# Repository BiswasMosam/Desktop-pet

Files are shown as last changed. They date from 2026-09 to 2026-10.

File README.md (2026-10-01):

# Desktop-pet

A tiny desk companion with a face. Two rounded eyes on a 0.96" OLED that glance around, blink, fidget, light up when you pet it and doze off when you ignore it. Plugged into the PC it becomes the physical face of [Aminal](https://github.com/BiswasMosam/Aminal-Public), my voice assistant: its eyes listen, think and talk along with it, and it shows the time, the weather, timers and reminders.

It follows the PC too: it dances to your music, eats popcorn through films, puts on glasses while you code, picks up a controller when you play, and counts down your selfies. And it doesn't need the cable: on a charger it reaches the PC over WiFi, and with the PC off it fetches its own time and weather.

<p>
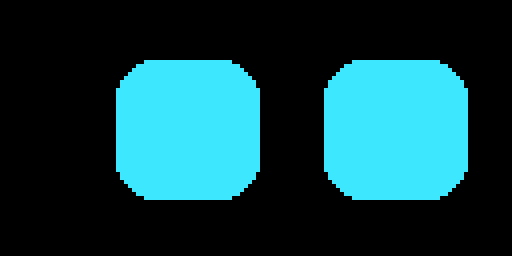
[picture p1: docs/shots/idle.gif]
Idle: glancing around and blinking
  
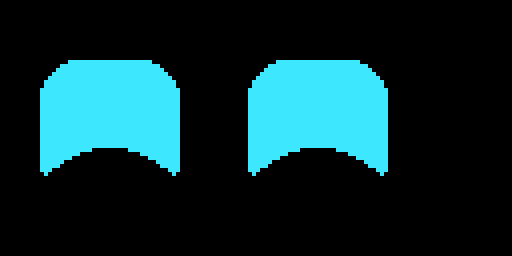
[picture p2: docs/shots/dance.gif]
Dancing to music, notes floating up
  
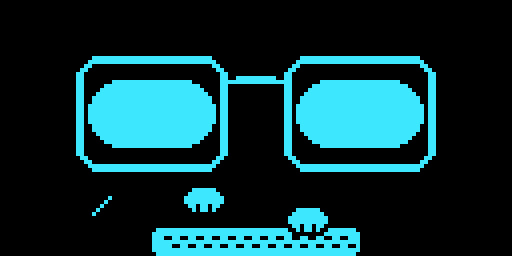
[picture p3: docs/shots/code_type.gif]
Coding: glasses on, paws typing
  
</p>

Real captures from the pet's own frame buffer: idle, dancing, and typing along while you code.

**[The handbook](https://www.mosambiswas.com/Desktop-pet/)** is the full user guide and technical notes: every face, trick and screen, the wiring, the firmware, the protocol and how it hears music. It's also a 25-page [PDF](docs/Desktop-pet-Handbook.pdf).

## What it does

### The face

| Expression | When | What you see |
| --- | --- | --- |
| **Idle** | Default | Glances around every 1.5 to 4 s, blinks, and every 15 to 40 s fidgets: a look around, a little hop, a suspicious squint or a double blink |
| **Happy** | You tap KEY | Eyes lift and curve into `^ ^` arcs for 2.5 s |
| **In love** | Three taps in a row | Beating hearts |
| **Sleepy** | 30 s with no attention (10 s after 11 pm) | Eyes droop into slits, `z`s bob in the corner, and the time shows small in the other |
| **Listening** | Aminal is listening | Eyes wide open, swelling with your voice |
| **Thinking** | Aminal is working it out | Looking up and off to one side, three dots filling in |
| **Speaking** | Aminal is talking | Eyes lifted, and a mouth that opens with Aminal's voice |

Aminal can also make it pull a face on request: happy, love, surprised, sad, angry, wink or sleepy.

Everything moves by easing the current eye position, width and height toward a target every frame, so glances glide, blinks snap shut and falling asleep is a slow droop rather than a jump cut.

### The other screens

- **Clock:** big time, the date, and a hairline filling across the minute.
- **Weather:** an animated icon (turning sun, crescent moon at night, falling rain, drifting snow, flickering lightning, rolling fog), the temperature, today's high and low, and the place.
- **Timer:** the countdown with a bar draining under it. It blinks while paused, and when it runs out the whole screen flashes "Time's up" until you tap it.
- **Claude:** how much of your Claude plan is used, the way Claude's own Usage settings show it: the current session and the week, each with a bar and when it resets. From 90% the number turns over, white on black. The bridge reads it every 2 minutes with the sign-in Claude Code keeps on the PC, and only the four numbers reach the pet. The page joins the round once there are numbers to show.
- **Status:** which link it's on, what Aminal is doing, and how fresh the time and weather are.

Reminders, mail and what's next on the calendar slide down as a card over whatever is on screen. Ask Aminal for the weather or a timer and the pet flips to that screen while it answers.

### Music and films

When Aminal hears Spotify playing, the pet joins in, in one of three moods picked at random and rerolled every 25 to 45 s:

| Mood | What you see |
| --- | --- |
| **Headphones** | Headphones on, eyes shut and happy, nodding on every beat, with a peek around now and then |
| **Dancing** | Swaying side to side and hopping on the beat, music notes floating up |
| **Visualizer** | The whole screen becomes 16 bars of what the speakers are actually playing, with falling peak marks |

Put on Netflix, Prime Video or Hotstar and it looks up at the screen with a bucket of **popcorn**, flicking a kernel into its mouth and chewing every few seconds. When a scene suddenly gets loud it jumps, and the popcorn flies out of the bucket.

Aminal decides music or film by the app and the tab title, never by guesswork, so a video call gets no reaction at all. The beats and bars come from Aminal listening to the speakers; without them the pet dances to a steady 115 bpm of its own.

### Coding and gaming

The pet also follows what's in front on the PC:

| In front | What you see |
| --- | --- |
| **Code** (VS Code, Cursor, a JetBrains IDE, a terminal, GitHub or Colab in a browser) | Glasses on, reading along each line and down the page. While you type, two paws tap on a little keyboard and code flies off its ends |
| **A game** (anything from a Steam, Epic, Riot, Xbox, EA, Ubisoft, GOG or Rockstar library, a few by name, or any exclusive full screen 3D app) | Eyes narrowed in focus and darting after the action, a controller in its hands with the buttons getting mashed. When the game gets loud, sparks burst out and the eyes pop wide |

With music playing as well it keeps the coding or gaming face and puts the headphones on over it, nodding on the beat. An editor nobody has touched for five minutes isn't coding, and a few seconds in front are needed before either counts, so alt-tabbing past VS Code changes nothing. Aminal goes by the program, its folder and the window title only, never by what's in the window or what's typed.

### The card

Tap the RFID card on the reader and a hidden folder opens on the PC (`C:\Users\<you>\Vault`, hidden and marked as a system folder so it stays out of sight even with hidden files shown). Tap again and it closes. The first card ever tapped becomes the key; any other card gets a sad face. It works with Aminal closed, since the bridge does it.

A tap is the card arriving after being away for 1.5 s, so a card left lying on the reader counts once. Gestures (double tap, hold to lock) and a "hotel key slot" came first and both glitched: a card resting on the reader drops out of reading for over a second now and then. Hidden is not locked: anyone who types the path can open the folder.

### Selfies

Ask Aminal for a selfie and the pet turns into a camera. While the webcam opens and meters, its lens focuses and searches for you ("smile please!"). As Aminal says "Hold still - three, two, one", the numbers count down inside the lens, then "cheese!". The moment the photo is actually taken, the screen flashes white and the shutter blinks closed and open ("click!"), and it says "developing" until Aminal has the picture ready.

The flash is the real shutter, not a timer: the photo burst starts the instant "three, two, one" ends, and the bridge flashes the pet on exactly that, because the voice takes anywhere from 1.9 to 2.4 s to say it.

### The button

KEY (PA0) is the only input, or a TTP223 touch pad on B0 under the top of the [enclosure](enclosure/), which does exactly the same:

| Press | On the face | Anywhere else |
| --- | --- | --- |
| **Tap** | Pet it | Next screen |
| **Double tap** | Next screen | Next screen |
| **Hold** | Back to the face | On the timer: pause or resume it. Elsewhere: back to the face |

A tap also dismisses a card. A screen you flipped to returns to the face after 20 s.

## Hardware

- **WeAct Black Pill**, STM32F401CC or STM32F411CE
- **0.96" SSD1306 OLED**, 128x64, I2C
- **ESP-01** WiFi module (optional): its own time and weather when the PC is off, and the link to the PC with no cable
- **RC522** RFID reader (optional): tap a card to open a hidden folder
- **TTP223** touch sensor (optional): pet it by touching the top of its head
- USB-C cable

### Wiring

| OLED | Black Pill |
| --- | --- |
| VCC | 3V3 |
| GND | GND |
| SCL | B6 |
| SDA | B7 |

| ESP-01 | Black Pill |
| --- | --- |
| 3V3 (VCC) | 3V3, with **short direct wires**. **Never 5V**. Long breadboard jumpers made it brown out whenever its radio worked; short ones on the Black Pill's own 3V3 are fine |
| GND | G |
| EN (CH_PD) | A8 (the pet holds it high, which saves a 3V3 pin) |
| TX | A10 |
| RX | A9 |
| RST | B12 (lets the pet restart it) |
| GPIO0 | B13 (lets the pet start its bootloader) |

| RC522 | Black Pill |
| --- | --- |
| 3.3V | 3V3. **Never 5V** |
| GND | G |
| SDA | A4 |
| SCK | A5 |
| MISO | A6 |
| MOSI | A7 |
| RST | B1 (the pet drives it; left floating, the chip can sleep and stop answering) |
| IRQ | not connected |

| TTP223 | Black Pill |
| --- | --- |
| VCC | B14 (it draws microamps, so a pin powers it) |
| GND | B15 |
| I/O | B0 (not A0: the bootloader reads A0 at reset, and the pad's output sits low) |

The board has three 3V3 pins and three G pins (two on the long headers, one each on the small 4-pin header): one pair each for the OLED, the ESP-01 and the RC522. Both 5V pins stay empty.

The ESP-01's pins aren't labelled on top. With the chips facing you and the antenna up, one row holds GND, GPIO2, GPIO0 and RX, the other TX, EN, RST and 3V3; GND and 3V3 sit at opposite corners. GPIO2 stays empty.

The KEY button (PA0) and the blue LED (PC13) are already on the board.

### The enclosure

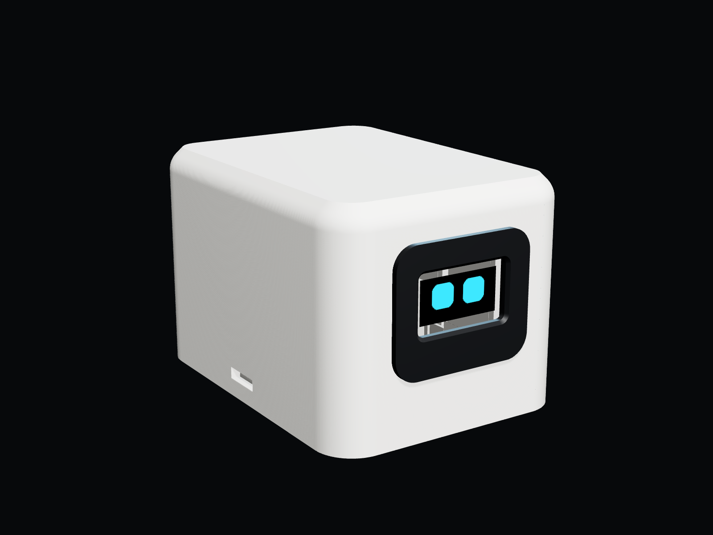
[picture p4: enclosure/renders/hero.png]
The pet in its printed head
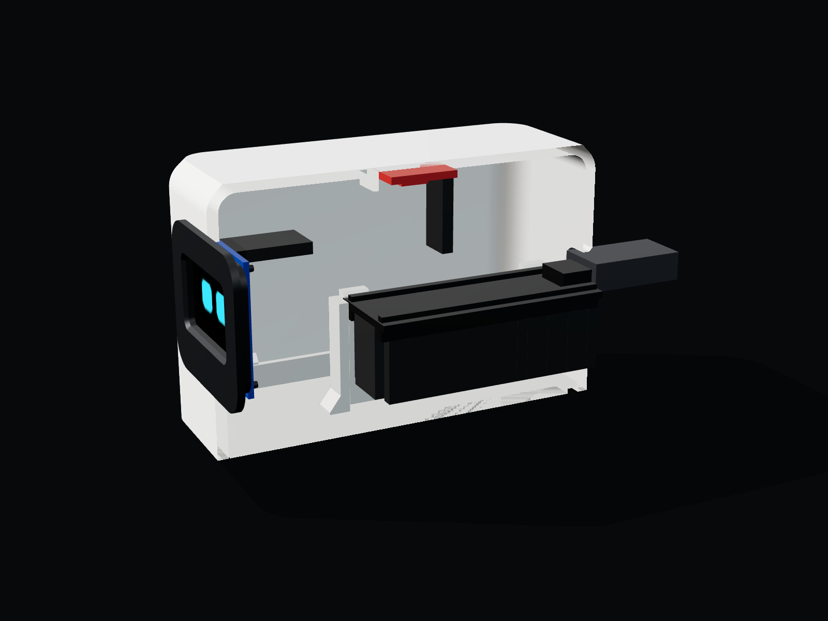
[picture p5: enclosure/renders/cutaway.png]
The head cut open
 

A 3D-printable head, 66 × 89.5 × 58 mm: a soft cube, the screen clamped behind a black visor, the Black Pill held up by its edges so its jumper plugs and SWD header hang free underneath, its USB-C lined up with a port in the back, the touch pad under the top, and the RFID reader hidden inside the right side, with nothing on the outside to give it away. Three parts, no supports. The STLs, print settings and how to put it together are in [enclosure/](enclosure/).

## Getting it running

WeAct Black Pills ship with the **WeAct HID bootloader** in the first 16 KB of flash. It shows up in Windows as a plain HID device (`0483:572A`), so it needs no driver and no Zadig, and it sidesteps the chip's built-in USB bootloader, which often fails with *Device Descriptor Request Failed*. The project is linked to start at `0x08004000`, right after it.

1. **Install PlatformIO.** In VS Code, open Extensions, search for *PlatformIO IDE*, install it and let it finish its first time setup.
2. **Get the uploader.** Download [`WeAct_HID_Flash-CLI.exe`](https://github.com/WeActStudio/WeActStudio.MiniSTM32F4x1/tree/master/Soft/WeAct_HID_FW_Bootloader) from WeAct's repo and save it as `tools/WeAct_HID_Flash-CLI.exe` in this folder. It's WeAct's own tool, closed source, so it isn't committed here.
3. **Open the project.** File > Open Folder > `Desktop-pet`. PlatformIO fetches the STM32 toolchain and the Adafruit display libraries on its own.
4. **Enter the bootloader.** A fresh board is already in it. Once your code is on it, hold **KEY**, tap NRST, wait for the blue LED to blink, then release KEY.
5. **Upload.** Click the → arrow in the blue status bar.
6. The eyes appear. If they don't, tap NRST.

The default build targets the F401CC and also runs on an F411CE. For the F411's full 100 MHz, read the square chip and, if it says `STM32F411CE`, change `default_envs` in `platformio.ini` to `blackpill_f411ce`.

### Connecting it to Aminal

A small bridge on the PC finds the pet on USB by its identity (`0483:5740`) and starts talking. It starts at login and runs whether Aminal is open or not, so the pet follows the music, films, code and games on the PC all day and gets the time, weather and timers; Aminal only adds its listening, thinking and speaking faces. If the bridge isn't running, Aminal starts it.

The cable isn't needed. With only a power cord on the pet, the bridge reaches it over WiFi: the ESP-01 listens on port 7676 and the bridge speaks the same protocol to it as over USB. It learns the pet's address whenever it's plugged in, and searches the home network for it if that address stops answering. USB always wins when it's plugged in. Anyone on the same network can reach that port too, so it's meant for a home network; joining WiFi (`WF`) and the ESP passthrough (`ES`) stay USB only. It can also save exactly what the OLED shows as a PNG (`SN`) or send the pet a single line. Aminal's code is private; its own README has the exact commands.

### WiFi

The ESP-01 keeps its factory **AT firmware**, and the pet drives it with plain text commands: join the network, then one plain-HTTP request to Open-Meteo every 20 minutes. That single reply carries the time (its `Date` header), the UTC offset and today's weather, so a pet running from a charger keeps its clock and forecast with the PC off. Where the weather is for (`LO`, sent by Aminal) and the UTC offset are kept in the Black Pill's flash across power cuts.

It also listens on port **7676** for the bridge, which is how the pet works with only a power cord (above). The module's multi-link mode makes that possible: the weather request goes out on link 4 while the bridge comes in on another. While the bridge is connected over WiFi it sends the time and weather itself, so the pet skips its own request. The pet resets the module at every boot, and again if it stops answering, so a bad power-up can't leave the WiFi stuck.

To connect it, run the bridge's WiFi setup with the pet on USB. It offers the network the PC is on, asks for the password without showing it, and sends both down the USB cable only. The module keeps them and rejoins by itself from then on. The ESP8266 only does **2.4 GHz** networks.

Reflashing the ESP-01 with firmware of its own, through the pet, was tried and failed: its ROM loader restarts on every esptool SYNC. The pet can still talk to it directly for debugging (`ES talk`), and every reset it does reports the ROM's own start-up line (`ES boot ets Jan 8 2013,rst cause:2, boot mode:(3,6)`), read at 74880 baud.

USB always wins. The bridge tries the cable first and WiFi every 15 s while the pet isn't plugged in, and plugging the cable back in moves the link to USB by itself. Running the pet from a phone charger or power bank is how it goes wireless: about 20 to 30 s after it powers up, the bridge reaches it over WiFi. Everything works over WiFi: a full `SN` snapshot takes about 0.4 s.

## The protocol

One short line per message, the same on USB and WiFi, simple enough to type into a serial monitor:

| Line | Meaning |
| --- | --- |
| `HI` | Who are you? The pet answers `PET desktop-pet 11` |
| `IP` | Its WiFi address: `IP 192.168.1.12`, or `IP -` when it isn't online |
| `PG` | Heartbeat, answered `PO`. Eight silent seconds and the pet is on its own again |
| `ST idle\|listening\|thinking\|speaking\|off` | What Aminal is doing |
| `LV 0-100` | Voice level, for the eyes and the mouth |
| `TM <unix> <utc offset s>` | The time |
| `WX <temp> <wmo code> <hi> <lo> <place>` | The weather |
| `TI <left s> <total s> <paused 0/1> <label>` or `TI -` | The timer, or none |
| `AL <secs> <title>\|<text>` or `AL -` | A card, or take it down |
| `EM <happy\|love\|surprised\|sad\|angry\|wink\|sleepy> [ms]` | Pull a face |
| `GO <face\|clock\|weather\|timer\|usage\|status> [secs]` | Show a screen |
| `CU <session %> <reset> <week %> <reset>` | Claude's usage, each reset as Unix time |
| `SN` | Answered `SN <hex>`: the 1024-byte frame buffer, exactly what's on the OLED |
| `RF`, `RF test`, `RF poll` | The RC522: its chip version; a wiring test (a register written and read back, and whether anything drives MISO); one try at reading a card |
| `MD music [headphones\|dance\|bars]`, `MD watch`, `MD -` | What's playing; a mood can be asked for by name |
| `VZ <16 hex digits>` | Spectrum bars, 0 to f each, low to high |
| `BE` | A beat |
| `JS` | A sudden loud moment in a film or a game |
| `AC code [typing]`, `AC game`, `AC -` | What's in front on the PC |
| `SF ready`, `SF count <ms>`, `SF shot`, `SF -` | A selfie: the camera opening, the spoken countdown, the shutter, done |
| `LO <lat> <lon> <place>` | Where the weather is for; kept in flash for the WiFi to use |
| `WF <ssid><tab><password>` | USB only: join a WiFi network (the ESP-01 keeps it) |
| `ES talk\|flash [baud]`, `ES reset` | USB only: the cable straight through to the ESP-01, in its own program or its bootloader, until 12-30 s of quiet |

The pet sends events back: `EV pet`, `EV next <screen>`, `EV hold`, `EV hold timer`, `EV dismiss`, `EV wifi ok <ip>`, `EV wifi fail`, `EV card <uid> tap`.

## Troubleshooting

| Symptom | Likely cause |
| --- | --- |
| Blue LED blinks fast, screen blank | OLED not found on I2C. Check the four wires, then try `0x3D` for `OLED_ADDR` in `src/main.cpp`. |
| Upload can't find the board | Board isn't in the HID bootloader. Hold KEY, tap NRST, release KEY when the LED blinks. |
| Upload says the command isn't found | `tools/WeAct_HID_Flash-CLI.exe` is missing (step 2). |
| No HID device at all, even holding KEY | The HID bootloader was erased (a DFU or ST-Link upload to `0x08000000` does that). Reflash it from WeAct's repo, or drop `board_build.flash_offset` and upload over DFU or ST-Link instead. |
| Don't install WinUSB over *WeAct Studio HID Bootloader* in Zadig | The uploader talks to it as HID. If you already did, uninstall that device in Device Manager and replug. |
| Garbage or noise on screen | Module may be an SH1106 (common on 1.3" boards), which needs a different library. |
| Eyes never react to Aminal | Status screen says `Link none`: the bridge isn't running, or something else (a serial monitor) has the port open. |
| ESP-01 answers `AT` but garbles its replies, restarts or goes silent while joining or scanning | Brownout. Its radio pulls ~300 mA bursts: serial turns to garbage (`AT+CWLAP` echoed as `AfWLAP`), then it crashes. Lowering its transmit power (`AT+RFPOWER`) didn't help. The cause here was the wiring, not the regulator: long breadboard jumpers drop too much voltage under those bursts, and short direct wires fixed it. If it still drops out on short wires, give it its own **AMS1117-3.3** on the 5V pin with a 470 µF capacitor. |

## How the code is laid out

| File | What's in it |
| --- | --- |
| `src/pet.h` | The shared `World`: time, weather, timer, Aminal's state, the current card |
| `src/main.cpp` | Setup, the frame loop, the button, switching screens |
| `src/face.cpp` | Eyes, moods, fidgets, and the listening, thinking and speaking faces |
| `src/screens.cpp` | Clock, weather icons, timer, Claude's usage, status, and the alert card |
| `src/media.cpp` | Headphones, music notes, the visualizer, and the popcorn |
| `src/activity.cpp` | Glasses, the keyboard and paws, the controller, and the sparks |
| `src/camera.cpp` | The camera face for a selfie: countdown, flash and shutter |
| `src/rfid.cpp` | The RC522: polling for a card, and turning a card's arrival into a tap |
| `src/link.cpp` | The protocol, read from USB and WiFi alike, and the ESP-01 passthrough |
| `src/wifi.cpp` | The ESP-01 driven through its AT firmware: joining, the HTTP request, reading the reply |

All timers compare with `reached(now, t)` instead of `now > t`, so the pet keeps blinking after `millis()` wraps around at about 49.7 days.

The saved location lives in the chip's last flash sector (0x08020000 on the F401CC). The app starts at 0x08004000 and is about 98 KB, so it has about 14 KB of room before the two would meet.

## Stack

C++ on the Arduino framework (STM32duino), built with PlatformIO. Adafruit SSD1306 and Adafruit GFX for the display, FreeSans Bold for the big digits.

## Next

- The touch pad, once it arrives (the firmware already powers and reads it)

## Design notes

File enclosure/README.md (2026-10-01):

# The enclosure

A head for the face: a soft cube, the screen behind a black visor, the Black Pill up on a stand inside, a touch pad under the top so you pet it where you'd pet a pet, and the RFID reader hidden inside its right side, so you tap your card on its cheek. Nothing on the outside gives it away.

The pet in its head

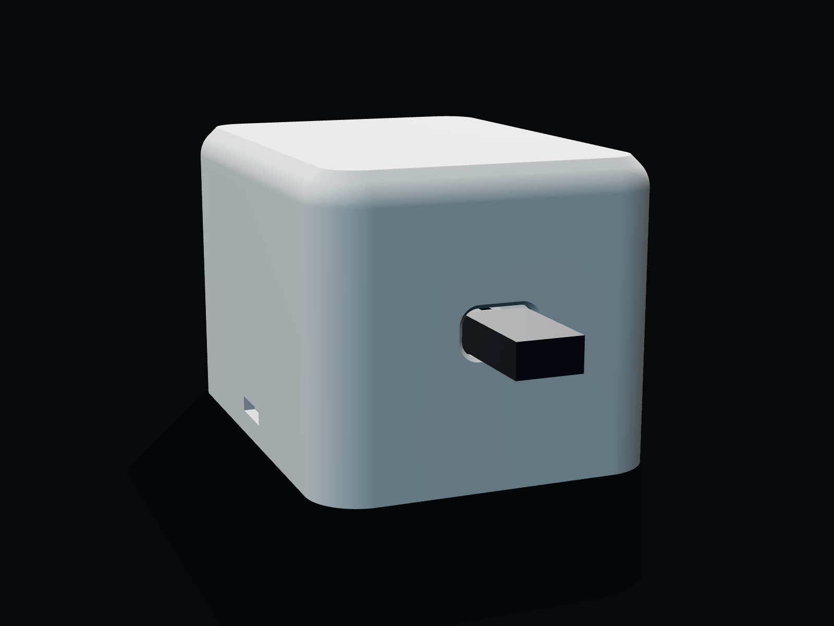
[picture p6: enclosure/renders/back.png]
From the back, with the USB-C cable in
|  | Cut open |
| --- | --- |
| The USB-C port in the back, lined up with the Black Pill's connector | Inside: the screen behind the visor, the Black Pill on its stand with its jumper plugs hanging underneath, the touch pad under the top |

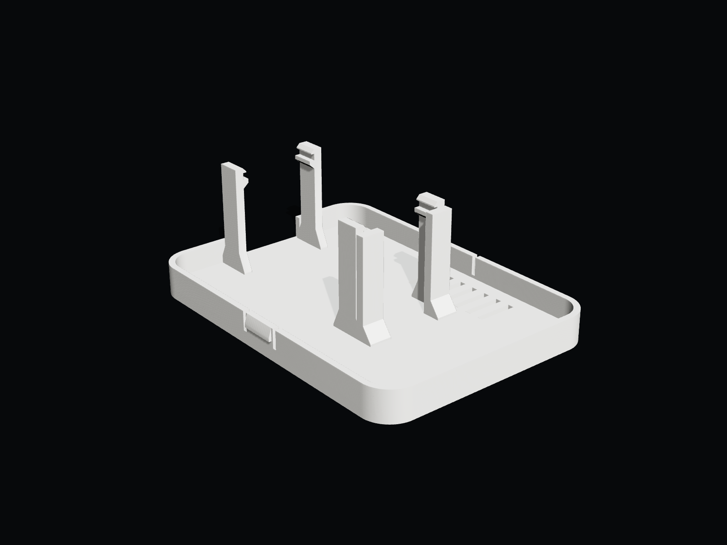
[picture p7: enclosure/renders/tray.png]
The base
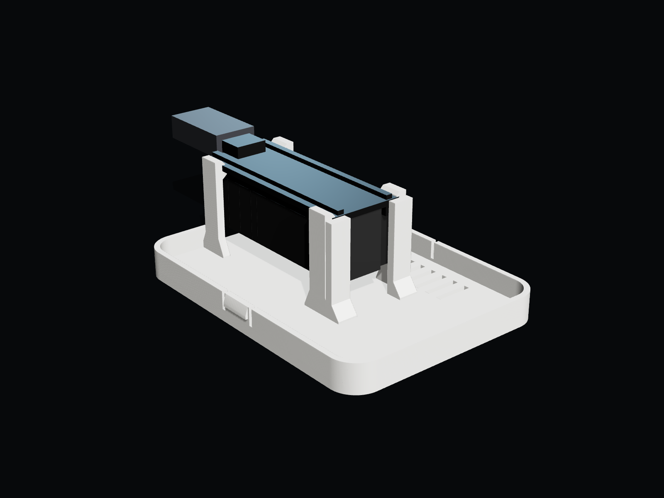
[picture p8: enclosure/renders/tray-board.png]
The base with the Black Pill in
|  |  |
| --- | --- |
| The base: four posts that hold the Black Pill by its edges, the front two wrapping round its corners | The board on them, chip side up, its plugs and the SWD header hanging free underneath |

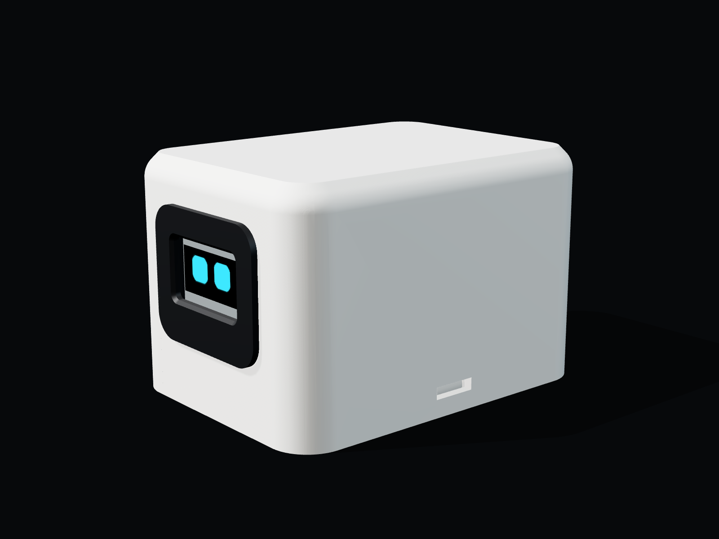
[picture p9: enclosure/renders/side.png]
The right side: smooth, with the reader behind it
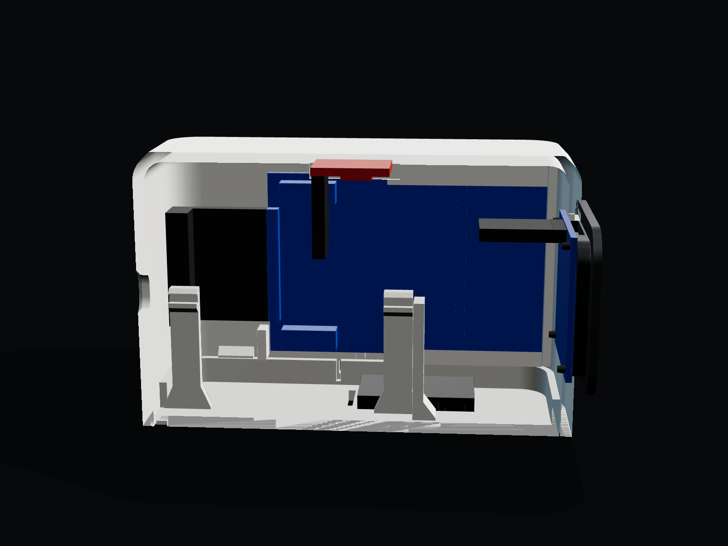
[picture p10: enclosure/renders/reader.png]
Inside the right wall: the reader in its holder
|  |  |
| --- | --- |
| The right side: smooth, the reader behind it. Tap the card near the front half | Inside the right wall: the RC522 in its holder, antenna end at the front, its plugs toward the back |

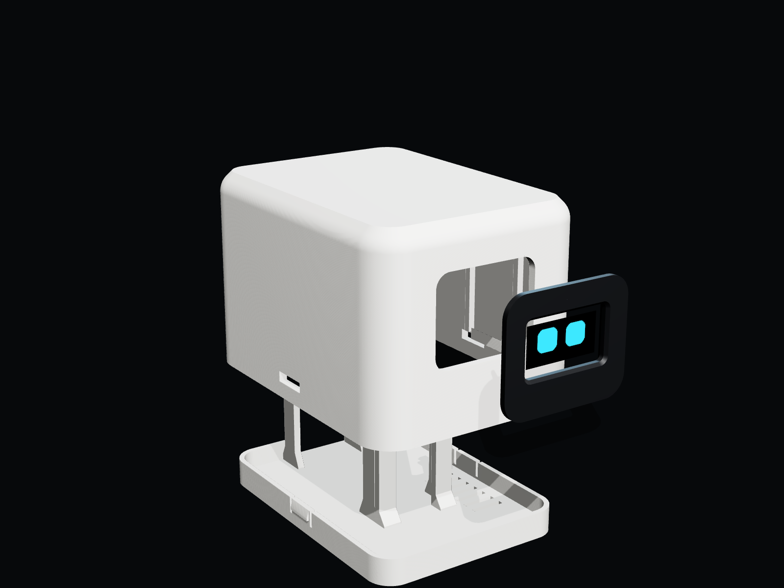
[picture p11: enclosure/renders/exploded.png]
Exploded


**66 × 89.5 × 58 mm.** It was 70 mm deep until the RFID reader went in: the RC522 is 60 mm long, its jumper plugs carry on 16 mm past its end, and the wires need a few more to turn, all between the head's round corners. The depth is worked out from those numbers in `model.py`, not typed in. Everything is modelled in [`model.py`](model.py) from the WeAct board drawing and the OLED module's dimensions, and [`check.py`](check.py) fits it all together with stand-ins for the boards, a jumper plug on every one of the Black Pill's 40 pins, the SWD header (straight with a plug on it, or right-angle), a USB-C plug pushed fully home, and the RC522 with its plugs and crystal (either way up): nothing overlaps.

## The Black Pill's stand

The Black Pill goes in the way it's wired: chip, buttons and USB-C on top, headers pointing down, every jumper plug hanging underneath, and the 4-pin SWD header on that side too, in the middle of the far end. So it sits 23.5 mm up, held only by its edges:

- **Four springy posts** stand outside the rows of plugs. Each has a ledge under the board's edge, in the 1.5 mm strip between the edge and the yellow header strip, and a clip over its top, so the board can't lift, drop or slide sideways.
- **The two front posts wrap round the board's corners.** They take the push when the USB cable goes in, and the back wall takes the pull when it comes out. Between them the far end is open, so the SWD header, and a plug on it if you ever want one, hangs free.
- **Nothing sits under the board.** The whole space between the two header strips is empty, down to the floor. The plugs end 7 mm above the floor, which leaves room for the wires to bend out to the sides.

Nothing reaches over the board's top except those four clips, so the buttons and the USB-C stay clear.

## The RFID reader's holder

The RC522 stands inside the right wall, long side front to back, its component side facing in. A card tapped on the outside reads through about 6 mm: the 2.4 mm wall, a 2 mm gap, and the board. There's no mark on the outside on purpose, since the card opens a hidden folder: the antenna is behind the front half of the side, about halfway up.

- **It hangs, it isn't screwed.** Its top edge sits in a slot under the roof, its bottom edge in a groove whose inner side slopes at 45°. To fit it, tilt it, push its top up into the slot (there's 2 mm to spare), swing the bottom in past the groove's edge and let it drop. A bit of tape behind it if you want it to never rattle.
- **The groove and the slot only grip the antenna end.** The crystal and the header sit at the other end, close to the edges, so nothing reaches over them.
- **Two ribs behind it and a stop at each end** keep it 2 mm off the wall, clear of the header's solder stubs, and stop it sliding.
- **It goes either way up.** Its header is off centre, so pick whichever way leaves the plugs easiest to reach.

## What to print

The STL files are already turned the way they go on the bed. **No supports** on any of them.

| Part | File | On the bed | Colour | Time* |
| --- | --- | --- | --- | --- |
| Head | [`stl/shell.stl`](stl/shell.stl) | Upside down, top on the bed | Any (white in the renders) | ~3.5 h |
| Visor | [`stl/visor.stl`](stl/visor.stl) | Face down | **Black**, so only the lit pixels show | ~15 min |
| Base | [`stl/base.stl`](stl/base.stl) | Flat | Any | ~1.5 h |

\*Rough, at 0.2 mm layers.

PLA or PETG, 0.4 mm nozzle, 0.2 mm layers, 15% infill. The walls are 2.4 mm, six lines, so they print solid anyway. The head's top edge is rounded where it shows and turns into a 45° chamfer where it meets the bed, so the first layers don't droop.

## What else you need

- **A TTP223 touch sensor module** (the small 15 × 11 mm one). It sits under the thinned top and senses your finger through 1 mm of plastic. For the bigger 24 × 24 mm round one, set `TOUCH_L` and `TOUCH_W` to 24 in `model.py`.
- **3 more jumper wires** for it.
- **The RC522** with its plugs on, wired as in the main README.
- A drop of superglue (or a soldering iron) for the visor's four pegs.
- The new firmware, which reads the touch pad on **B0** (upload it as usual; with the base out, KEY and NRST are right there on top of the board).

## Putting it together

1. **Print the visor first** and check the screen before printing anything else. Press the OLED onto its four pegs, glass into the recess, then power the pet and double tap to the **Status** screen. The whole top line (*Desktop pet … USB*) and bottom line (*Up …*) should show through the window. If a line is cut off, measure roughly how far and change `AA_UP` in `model.py` (positive moves the window up). Then take the OLED off again.
2. **Screen into the head.** Push the visor into the face from the outside. Reach in through the open bottom, put the OLED onto the pegs and glue or melt each peg tip. The screen is now clamped through the wall and can't move.
3. **The RFID reader into the right wall,** component side facing in, antenna end toward the face, plugs already on and pointing back. Tilt it, top edge up into the slot first, swing the bottom in and let it drop into the groove.
4. **Touch pad under the top.** Pad side up (the side without the chip), pins toward the back, into the pocket in the middle of the top. A bit of tape or glue holds it. Don't touch the head while the pet powers up: the TTP223 measures its "not touched" level then.
5. **Black Pill onto its stand,** with its jumpers already plugged in. USB end toward the back of the base (the end with the finger notch), chip side up, its far end against the two corner stops. Press it down between the four posts until all four clips snap over its edges. Bend the wires out to the sides under the board.
6. **The ESP-01** goes loose on the floor, on the right, over the vents.
7. **Wire everything** as in the main README, and the touch pad as below.
8. **Base into the head,** USB end at the back, until both catches click into the side windows. To open it again, press both catches in through those windows and pull the base down by the notch at the back.

### The touch pad's wiring

| TTP223 | Black Pill |
| --- | --- |
| VCC | B14 (the pet powers it from a pin: it draws microamps) |
| GND | B15 |
| I/O | B0 |

Touching it does everything KEY does: tap to pet, three taps for hearts, double tap for the next screen, hold to go back. KEY still works too. The pad isn't on KEY's own pin (A0), because the bootloader reads A0 at every reset, and a TTP223 holds its output low while nobody's touching it.

## Changing it

All the numbers are at the top of [`model.py`](model.py): the head's size and radii, the wall thickness, the clearance between parts (`FIT`), the OLED's hole spacing and the window, how high the Black Pill sits (`BP_LIFT`), the USB-C port, the touch pad, and the RFID reader (`RFID_*`, which also sets the depth).

```bash
pip install manifold3d trimesh numpy scipy
python model.py      # the STLs, into stl/
python check.py      # fits everything together and lists any overlap, writes assembly.glb
node render.mjs      # the pictures, into renders/ (uses headless Chrome)
```

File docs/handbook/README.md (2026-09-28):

# The handbook's source

The handbook lives at **https://www.mosambiswas.com/Desktop-pet/** (GitHub Pages, serving this repo's `docs/` folder) and as [`../Desktop-pet-Handbook.pdf`](../Desktop-pet-Handbook.pdf). Both are built from `handbook.src.html`, and every screen picture in them is a real capture from the pet.

| File | What it does |
| --- | --- |
| `pet.py` | Talks to the pet over USB and grabs frames with `SN` |
| `capture.py` | Drives the pet through every face and screen and records each as `shots/<name>.npz` (frame times plus 64x128 frames) |
| `render.py` | Turns the captures into the cyan GIFs (`site/shots/`) |
| `build.py` | Builds the site (`../index.html`, `../shots/`, `../og.png`), the A4 source `paper.html` (frame strips as vector pixels) and `site/index.html`, the same page without its document wrapper, for hosts that add their own |
| `print.mjs` | Prints `paper.html` to PDF with headless Chrome, through the puppeteer-core in `D:/Garage/Fill.ai/node_modules` |

## Rebuilding

1. **Only if the pet's look changed:** close Aminal (its bridge holds the pet's port), then `python3.12 capture.py`, or name groups: `python3.12 capture.py aminal music`. It takes about 2.5 minutes for everything.
2. `python3.12 render.py`, then `python3.12 build.py`. Pushing `docs/` updates the site.
3. `node print.mjs paper.html handbook.pdf`, then set the metadata and save it as `../Desktop-pet-Handbook.pdf`.

The build reads the pet's own 5x7 font from PlatformIO's copy of Adafruit GFX (`.pio/libdeps`), and the PDF uses the fonts in `D:/Garage/BiswasMosam.github.io/fonts/`, because headless Chrome here can't reach Google Fonts. The site loads the same families from Google Fonts.

When the document changes, bump the revision on the cover and in the footer, and add a row to its *Document history* table.

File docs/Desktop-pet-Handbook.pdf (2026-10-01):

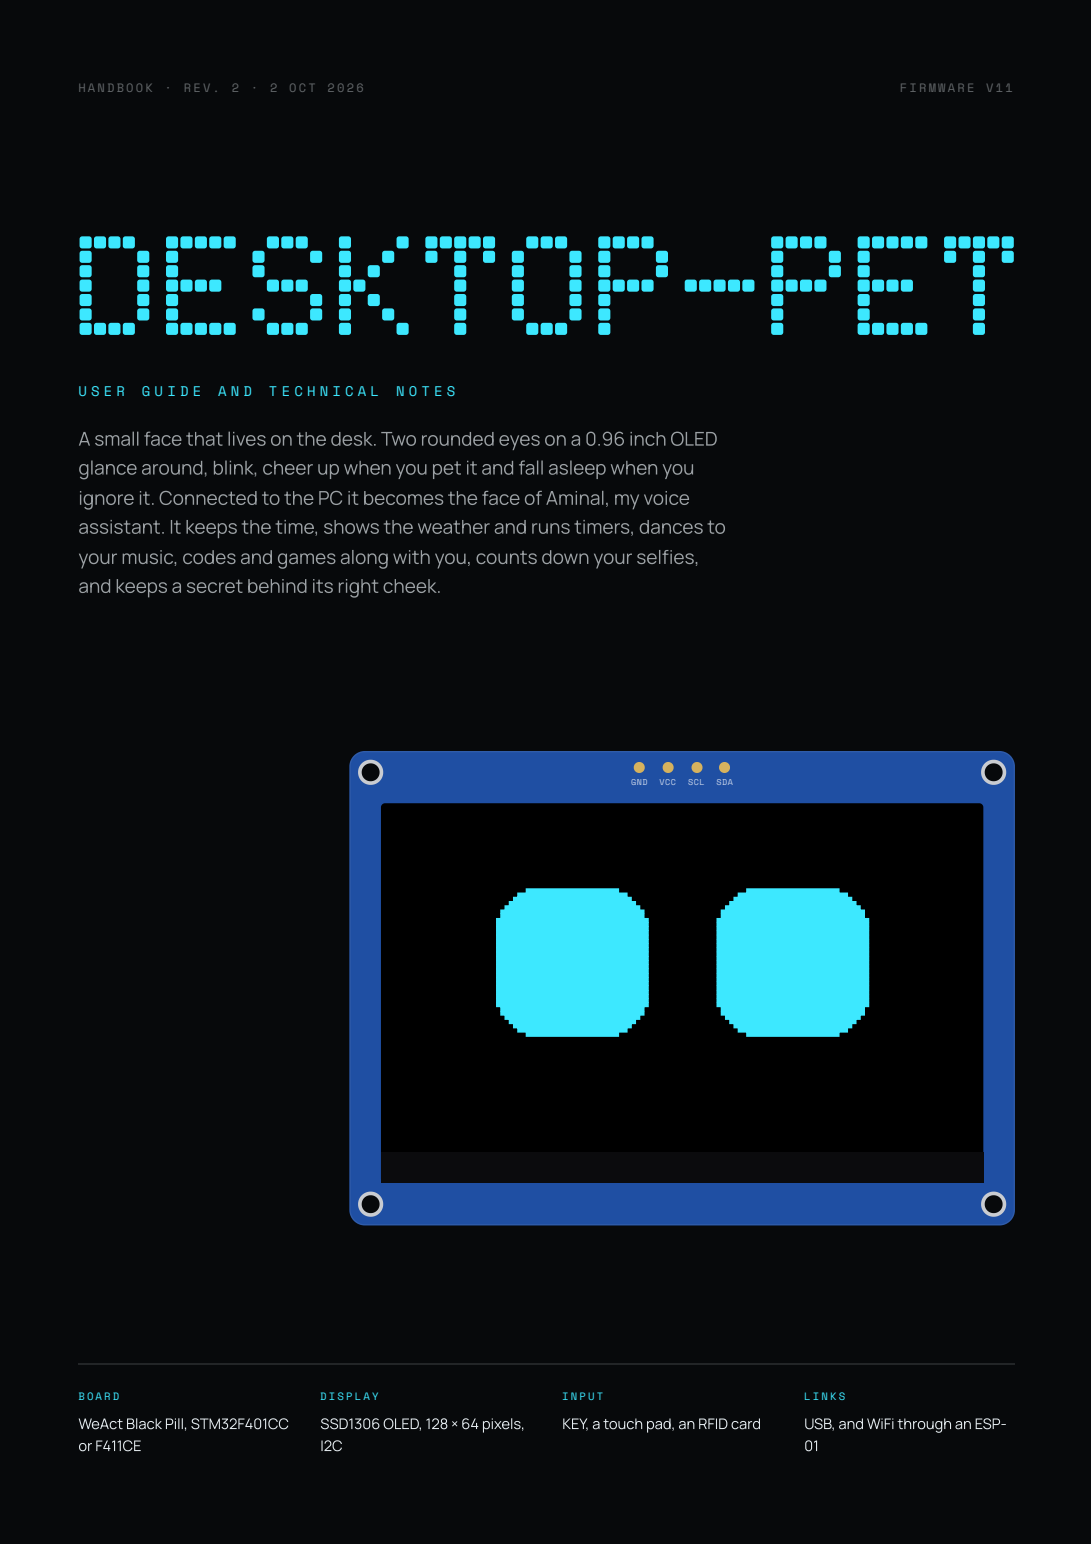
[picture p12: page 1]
SSD1306 OLED, 128 × 64 pixels,

A small face that lives on the desk. Two rounded eyes on a 0.96 inch OLED

glance around, blink, cheer up when you pet it and fall asleep when you

ignore it. Connected to the PC it becomes the face of Aminal, my voice

assistant. It keeps the time, shows the weather and runs timers, dances to

your music, codes and games along with you, counts down your selfies,

and keeps a secret behind its right cheek.

GND VCC SCL SDA

WeAct Black Pill, STM32F401CC

KEY, a touch pad, an RFID card

USB, and WiFi through an ESP-

D E S K T O P - P E T · H A N D B O O K · R E V . 2 | 02

C O N T E N T S

# WHAT'S INSIDE

G U I D E

### 01 Meet the pet

What it is and how it's connected

### 02 One button

Tap, double tap, hold

### 03 Left to itself

Moods, habits and the faces it can pull

### 04 Aminal's face

Listening, thinking, speaking

### 05 Music and films

Headphones, dancing, bars and popcorn

### 06 Coding and gaming

Glasses and paws, a controller and sparks

### 07 Selfies

A countdown, and a flash on the real shutter

### 08 The card

Tap it and a hidden folder opens

### 09 Screens and cards

Clock, weather, timer, status, alerts

### 10 Things to try

Tricks, and the details that are easy to miss

I N S I D E

### 11 How it fits together

The bridge, Aminal and the pet

### 12 Wiring

OLED, ESP-01, RC522, touch pad, power

### 13 The head

The printed enclosure

### 14 The firmware

The loop, easing, who gets the face, timings

### 15 The protocol

Every line, and how snapshots work

### 16 How it hears music

From the speakers to 16 bars and a beat

### 17 WiFi

Its own time and weather, and the link to the PC

### 18 Building and uploading

PlatformIO, the HID bootloader, flash layout

### 19 When something's off

Troubleshooting and a map of the code

A B O U T T H E P I C T U R E S

Every screen in this handbook is a real capture. The pet was asked for its frame buffer 28 times a second over USB (the SN command, chapter 15) and each 1,024-byte frame was drawn back pixel for pixel. Where a figure shows a strip, the

frames are in order and the times are measured from the first one. The time, the weather and the timers are example values sent to the pet for the pictures.

D E S K T O P - P E T · H A N D B O O K · R E V . 2 | 03

G U I D E · 0 1

# MEET THE PET

Desktop-pet is a face for the desk. It runs on a WeAct Black Pill, a thumb-sized board with an STM32 chip on it, and draws on a 128 × 64 OLED about the size of a postage stamp. You touch it through one button, called KEY, or a touch pad under the top of its head.

On its own it behaves like a small animal: it looks around, blinks, fidgets, enjoys being petted and dozes off when nobody pays attention. Connected to the PC it also follows what you're doing: it dances to your music, eats popcorn through films, puts on glasses while you code and picks up a controller when you play. It is the face of Aminal, my voice assistant, and a small dashboard for the time, the weather, timers and reminders.

On the PC a small bridge program does the talking. It starts when you log in and runs whether Aminal is open or not, so the pet follows the PC all day, and Aminal adds its listening, thinking and speaking on top.

H O W I T ' S C O N N E C T E D | W H A T I T D O E S
USB cable to the PC | Everything. The fastest link, always used when it's plugged in.
WiFi, on a charger | Everything, over the air. The bridge finds it about 20 to 30 seconds after it powers up.
A charger, PC off | Still a pet. Its WiFi module fetches its own time and weather.

D E S K T O P - P E T · H A N D B O O K · R E V . 2 | 04

G U I D E · 0 2

# ONE BUTTON

KEY is the small button beside the USB socket. The other one, NRST, restarts the
board. What a press does depends on what is on the screen.
P R E S S | O N T H E F A C E | O N A N Y O T H E R S C R E E N
Tap | Pets it: happy for 2.5 seconds | Next screen

Three taps Falls in love: two beating hearts. Each tap within 1.5 s of the
| last. | Three screens on

Double tap Pets it, then flips to the next screen. Second tap within 0.35

s.

Two screens on

Hold, 0.7 s Back to the face | On the timer: pause or carry on. Anywhere else: back to the
| face.

A tap also puts away a card. The screens come round in this order: face, clock,
weather, timer (only while one is running), Claude (once the bridge has sent its numbers) and status. A screen you flip to goes back to the face by itself after 20 seconds.

## Tap

## Double tap

## Hold

0 | 0.35 s | 0.7 s | 1 s

## pets it the moment you let go second tap within 0.35 s

## next screen

## acts here, still held

# LEFT TO ITSELF

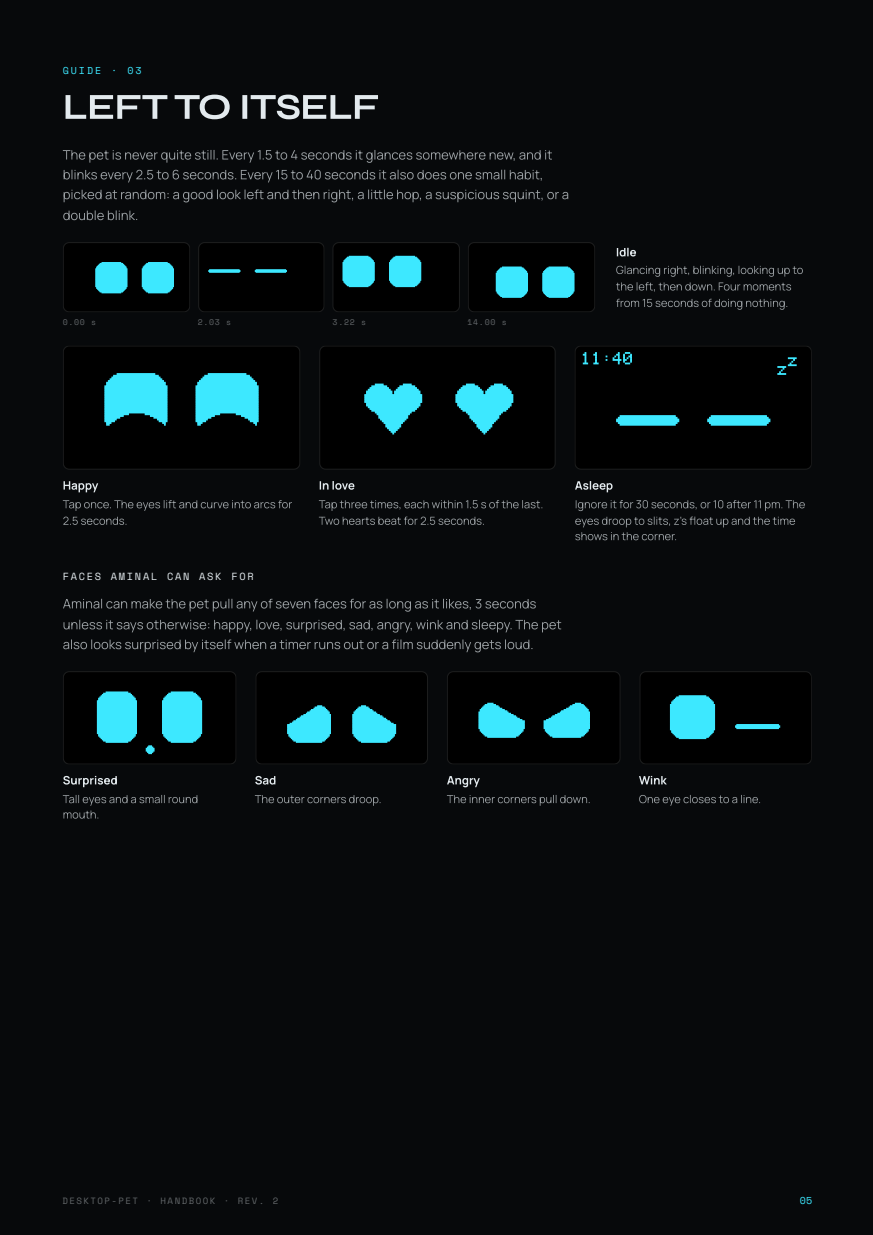
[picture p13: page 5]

The pet is never quite still. Every 1.5 to 4 seconds it glances somewhere new, and it
blinks every 2.5 to 6 seconds. Every 15 to 40 seconds it also does one small habit,
picked at random: a good look left and then right, a little hop, a suspicious squint, or a
double blink.

Idle
Glancing right, blinking, looking up to
the left, then down. Four moments
from 15 seconds of doing nothing.

Happy
Tap once. The eyes lift and curve into arcs for
2.5 seconds.

In love
Tap three times, each within 1.5 s of the last.
Two hearts beat for 2.5 seconds.

Asleep
Ignore it for 30 seconds, or 10 after 11 pm. The
eyes droop to slits, z's float up and the time
shows in the corner.

Aminal can make the pet pull any of seven faces for as long as it likes, 3 seconds
unless it says otherwise: happy, love, surprised, sad, angry, wink and sleepy. The pet
also looks surprised by itself when a timer runs out or a film suddenly gets loud.

Surprised
Tall eyes and a small round
mouth.

Sad
The outer corners droop.

Angry
The inner corners pull down.

Wink
One eye closes to a line.

# AMINAL'S FACE

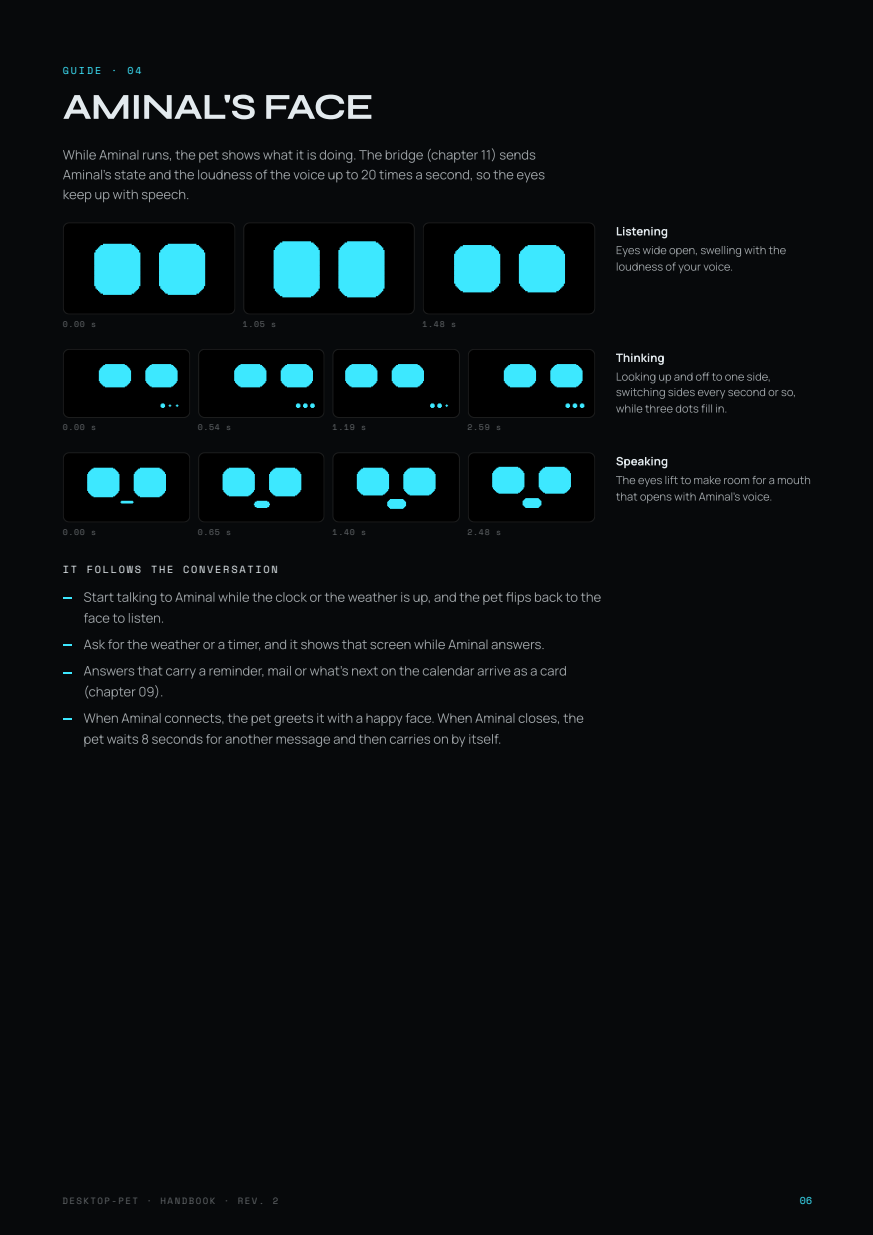
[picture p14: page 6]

While Aminal runs, the pet shows what it is doing. The bridge (chapter 11) sends
Aminal's state and the loudness of the voice up to 20 times a second, so the eyes
keep up with speech.

Listening
Eyes wide open, swelling with the
loudness of your voice.

Thinking
Looking up and off to one side,
switching sides every second or so,
while three dots fill in.

Speaking
The eyes lift to make room for a mouth
that opens with Aminal's voice.

Start talking to Aminal while the clock or the weather is up, and the pet flips back to the
face to listen.

Ask for the weather or a timer, and it shows that screen while Aminal answers.

Answers that carry a reminder, mail or what's next on the calendar arrive as a card
(chapter 09).

When Aminal connects, the pet greets it with a happy face. When Aminal closes, the
pet waits 8 seconds for another message and then carries on by itself.

# MUSIC AND FILMS

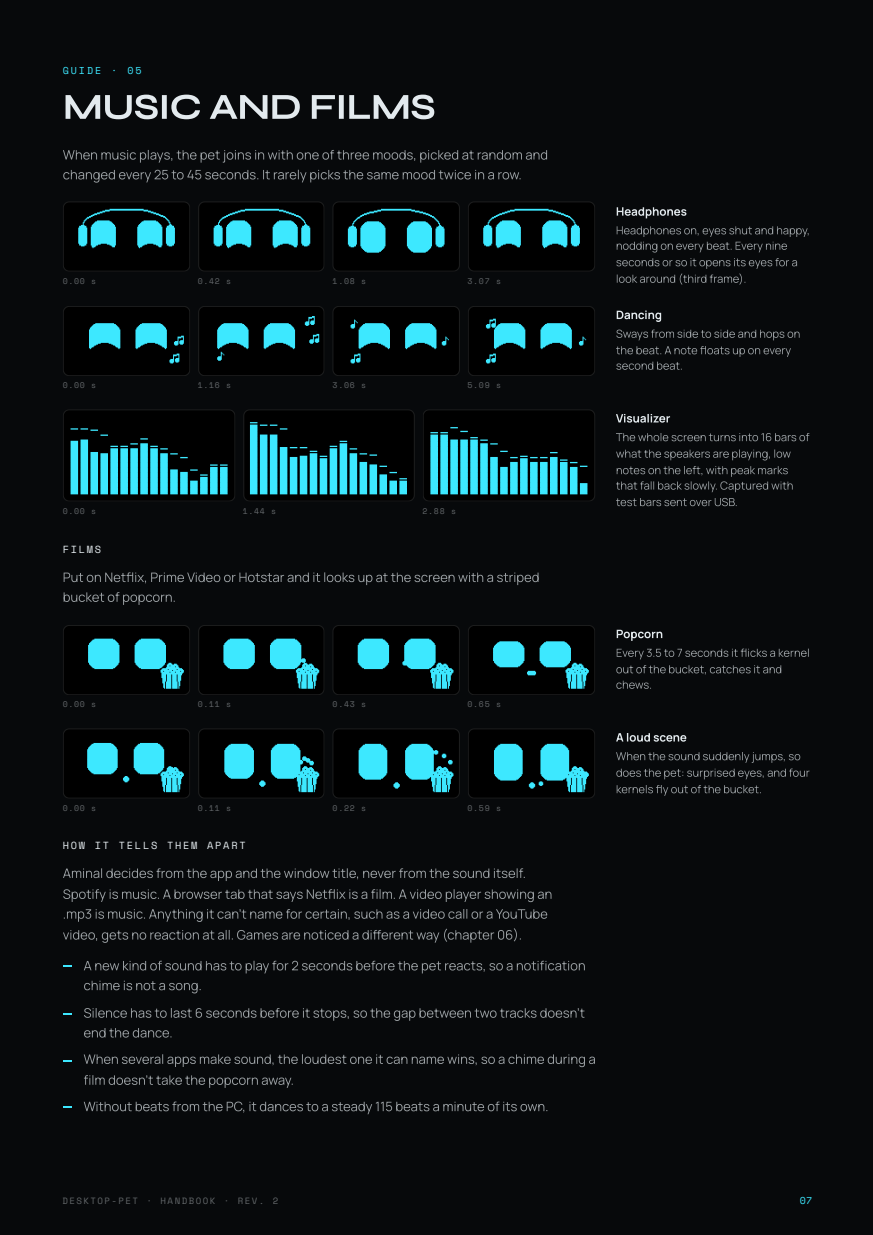
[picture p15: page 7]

When music plays, the pet joins in with one of three moods, picked at random and
changed every 25 to 45 seconds. It rarely picks the same mood twice in a row.

Headphones
Headphones on, eyes shut and happy,
nodding on every beat. Every nine
seconds or so it opens its eyes for a
look around (third frame).

Dancing
Sways from side to side and hops on
the beat. A note floats up on every
second beat.

Visualizer
The whole screen turns into 16 bars of
what the speakers are playing, low
notes on the left, with peak marks
that fall back slowly. Captured with
test bars sent over USB.

Put on Netflix, Prime Video or Hotstar and it looks up at the screen with a striped
bucket of popcorn.

Popcorn
Every 3.5 to 7 seconds it flicks a kernel
out of the bucket, catches it and
chews.

A loud scene
When the sound suddenly jumps, so
does the pet: surprised eyes, and four
kernels fly out of the bucket.

Aminal decides from the app and the window title, never from the sound itself.
Spotify is music. A browser tab that says Netflix is a film. A video player showing an
.mp3 is music. Anything it can't name for certain, such as a video call or a YouTube
video, gets no reaction at all. Games are noticed a different way (chapter 06).

A new kind of sound has to play for 2 seconds before the pet reacts, so a notification
chime is not a song.

Silence has to last 6 seconds before it stops, so the gap between two tracks doesn't
end the dance.

When several apps make sound, the loudest one it can name wins, so a chime during a
film doesn't take the popcorn away.

Without beats from the PC, it dances to a steady 115 beats a minute of its own.

# CODING AND GAMING

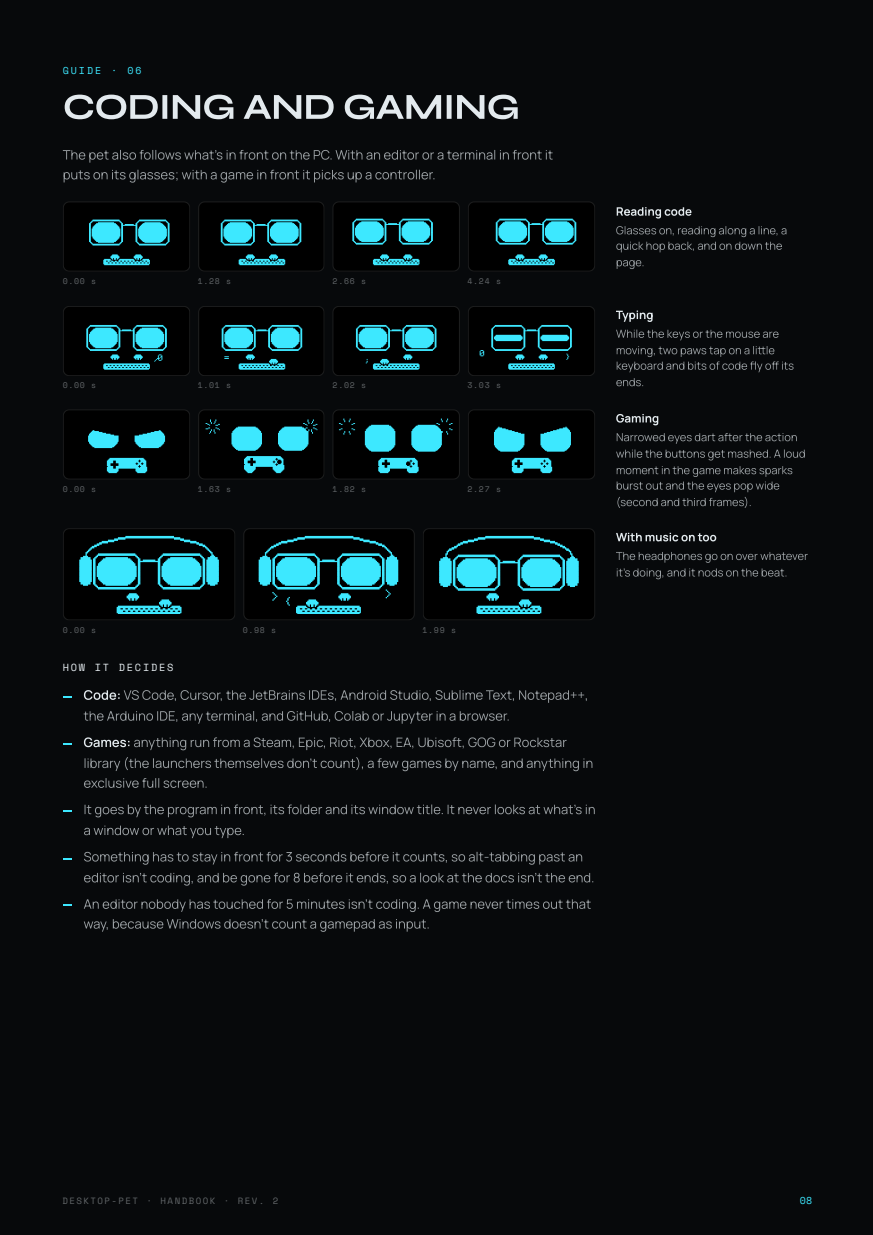
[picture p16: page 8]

The pet also follows what's in front on the PC. With an editor or a terminal in front it
puts on its glasses; with a game in front it picks up a controller.

Reading code
Glasses on, reading along a line, a
quick hop back, and on down the
page.

Typing
While the keys or the mouse are
moving, two paws tap on a little
keyboard and bits of code fly off its
ends.

Gaming
Narrowed eyes dart after the action
while the buttons get mashed. A loud
moment in the game makes sparks
burst out and the eyes pop wide
(second and third frames).

With music on too
The headphones go on over whatever
it's doing, and it nods on the beat.

Code: VS Code, Cursor, the JetBrains IDEs, Android Studio, Sublime Text, Notepad++,
the Arduino IDE, any terminal, and GitHub, Colab or Jupyter in a browser.

Games: anything run from a Steam, Epic, Riot, Xbox, EA, Ubisoft, GOG or Rockstar
library (the launchers themselves don't count), a few games by name, and anything in
exclusive full screen.

It goes by the program in front, its folder and its window title. It never looks at what's in
a window or what you type.

Something has to stay in front for 3 seconds before it counts, so alt-tabbing past an
editor isn't coding, and be gone for 8 before it ends, so a look at the docs isn't the end.

An editor nobody has touched for 5 minutes isn't coding. A game never times out that
way, because Windows doesn't count a gamepad as input.

# SELFIES

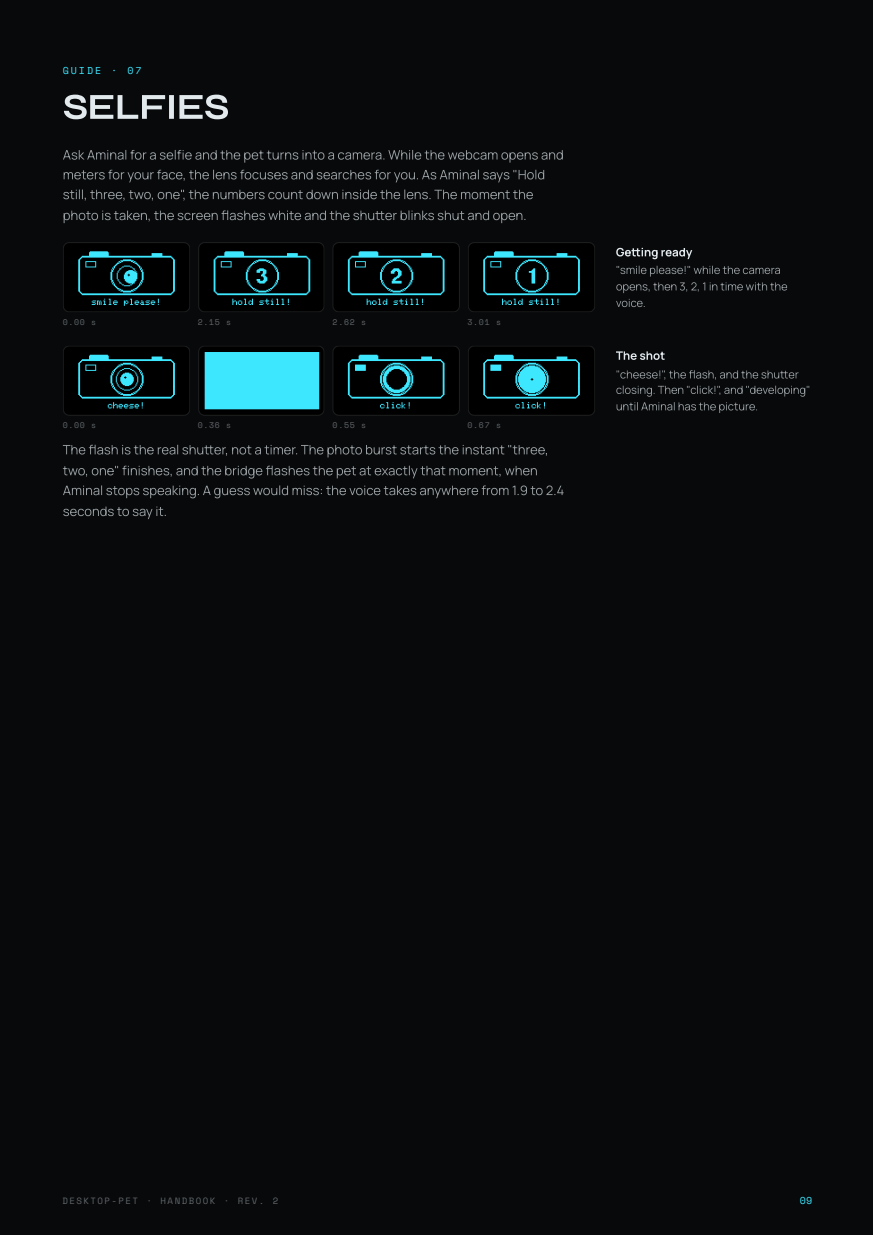
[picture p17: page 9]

Ask Aminal for a selfie and the pet turns into a camera. While the webcam opens and
meters for your face, the lens focuses and searches for you. As Aminal says "Hold
still, three, two, one", the numbers count down inside the lens. The moment the
photo is taken, the screen flashes white and the shutter blinks shut and open.

Getting ready
"smile please!" while the camera
opens, then 3, 2, 1 in time with the
voice.

The shot
"cheese!", the flash, and the shutter
closing. Then "click!", and "developing"
until Aminal has the picture.

The flash is the real shutter, not a timer. The photo burst starts the instant "three,
two, one" finishes, and the bridge flashes the pet at exactly that moment, when
Aminal stops speaking. A guess would miss: the voice takes anywhere from 1.9 to 2.4
seconds to say it.

D E S K T O P - P E T · H A N D B O O K · R E V . 2 | 10

G U I D E · 0 8

# THE CARD

An RFID reader hides inside the right side of the pet's head (chapter 13). Tap the white card from its kit on the right side, near the front, and a hidden folder opens on the PC. Tap again and it closes.

Folder open
The pet looks up in surprise, says what it did on a card, and the folder opens.

The first card ever tapped becomes the key. Any other card gets a sad face and "Not my card".

The folder is called Vault and lives in your user folder. It's made on the first tap and marked hidden and system, so it stays out of sight even with hidden files shown. Hidden isn't locked: anyone who types the path can open it.

A tap is the card arriving after being away for 1.5 seconds, so a card left lying on the reader counts once.

It works with Aminal closed: the bridge does it.

D E S K T O P - P E T · H A N D B O O K · R E V . 2 | 11

G U I D E · 0 9

# SCREENS AND CARDS

Clock
The time in big digits, the date above it, and a bar that fills across each minute.

Weather
An animated icon, the
temperature, today's high and low, and the place. After three hours without news it adds " (old)".

Timer
Counts down by itself between updates, over a bar that drains. Paused, it blinks like an oven.

Status
The link, what Aminal is doing, WiFi, how fresh the time and weather are, and how long it has been up.

C L A U D E ' S U S A G E

Claude
The current session and the week, as Claude's own Usage settings show them: how much is used, a bar, and when each resets. From 90% the number turns over, white on black.

W E A T H E R I C O N S

Every icon moves: the sun's rays turn, rain and snow fall, fog drifts and lightning flickers. From 7 pm to 6 am a clear sky shows a moon with twinkling stars. The numbers are the WMO weather codes Open-Meteo reports.

Clear

Code 0

Partly cloudy

Codes 1 and 2

Overcast

Code 3

Fog

Codes 45 and 48

Rain and showers

Codes 61 to 67 and 80 to 82; drizzle

(51 to 57) falls lighter

Snow

Codes 71 to 77, 85 and 86

Thunderstorm

Codes 95 to 99

Clear, at night

Code 0 from 7 pm to 6 am

The bridge reads the numbers every 2 minutes with the sign-in Claude Code keeps on the PC. Only the four numbers reach the pet; the sign-in never leaves the PC.

The bridge never renews that sign-in, since Claude Code owns it. If it has expired, the page keeps the last numbers, and after 20 minutes without news the title says "(old)".

The page only joins the round of screens once there are numbers to show.

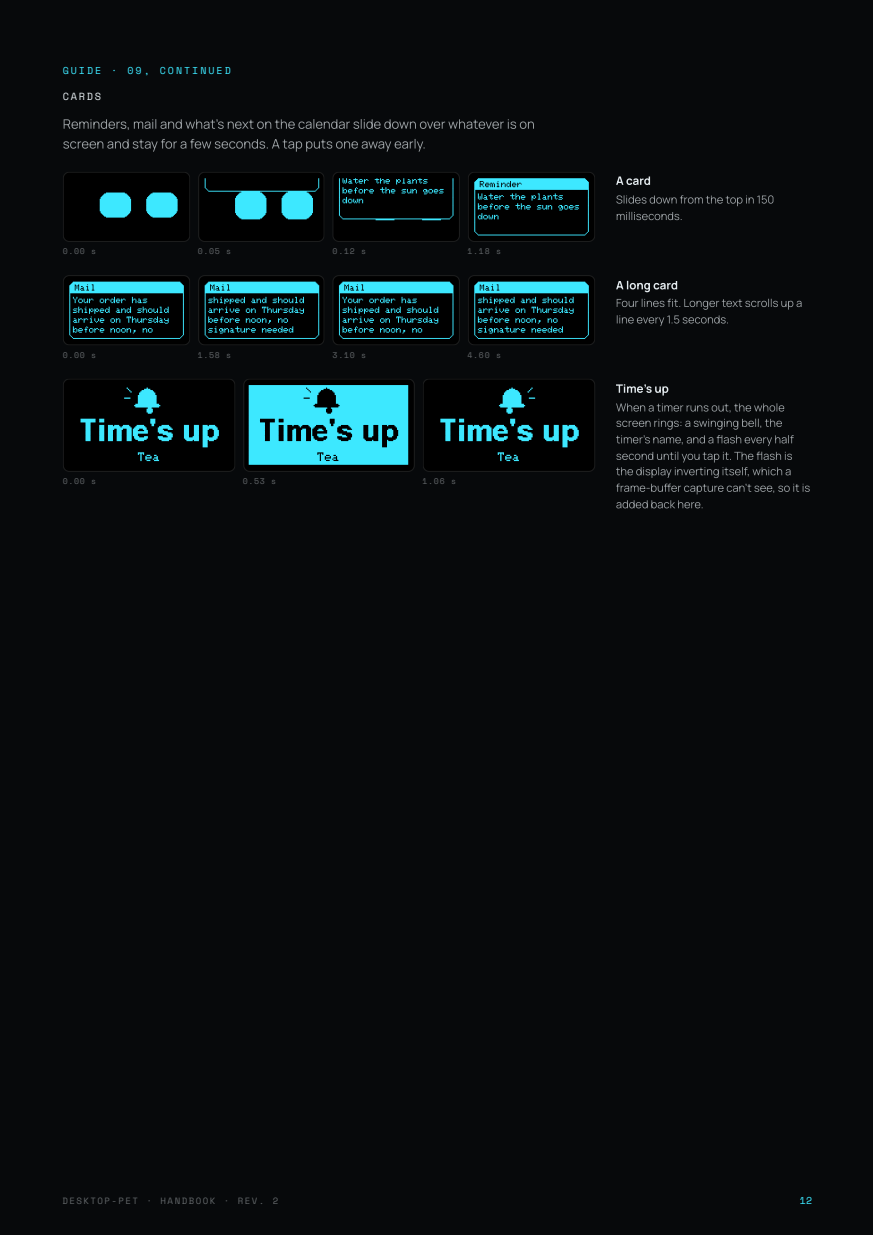
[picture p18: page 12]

Reminders, mail and what's next on the calendar slide down over whatever is on
screen and stay for a few seconds. A tap puts one away early.

A card
Slides down from the top in 150
milliseconds.

A long card
Four lines fit. Longer text scrolls up a
line every 1.5 seconds.

Time's up
When a timer runs out, the whole
screen rings: a swinging bell, the
timer's name, and a flash every half
second until you tap it. The flash is
the display inverting itself, which a
frame-buffer capture can't see, so it is
added back here.

D E S K T O P - P E T · H A N D B O O K · R E V . 2 | 13

G U I D E · 1 0

# THINGS TO TRY

Some of what the pet does only shows up when you go looking for it.

W I T H Y O U R F I N G E R

Pet it three times, fast.

Taps less than 1.5 seconds apart add up, and the third turns its

eyes into hearts.

Leave it alone.

After 30 seconds it droops off to sleep. One tap wakes it.

Check on it late at night.

After 11 pm it falls asleep after only 10 seconds and shows the

time while it sleeps, so it works as a night clock.

Double tap.

It walks through the clock, the weather, the timer, Claude's

usage and the status screen, then comes back to the face by

itself.

Hold it on the timer.

The timer pauses and blinks. Hold again to carry on.

Tap your card on its right cheek.

A hidden folder opens. Tap again and it closes.

W I T H A M I N A L

Talk while the clock is up.

It flips back to the face to listen.

Speak up.

The eyes grow with your voice.

Ask for a selfie.

It counts down with the voice and flashes at the exact moment

of the photo.

Close Aminal.

The pet keeps following your music, code and games. Only the

listening, thinking and speaking stop.

Run it from a charger.

The bridge finds it over WiFi within about 30 seconds. Plug the

cable back in and it moves back to USB by itself.

W I T H T H E P C

Play a long playlist.

The mood changes every 25 to 45 seconds: headphones,

dancing, or the visualizer.

Watch the headphones.

Every nine seconds or so it peeks out.

Skip a track.

A gap shorter than 6 seconds doesn't stop the dance.

Get a message during a film.

The chime doesn't take the popcorn away.

Open VS Code and type.

Glasses on, paws on the keys, code flying off the keyboard.

Code with music on.

The headphones go on over the glasses.

Start a game.

It picks up a controller. Loud moments make sparks.

Join a video call.

Nothing happens, on purpose.

S M A L L D E T A I L S

The bar under the clock

is the seconds, filling across the minute.

The sun's rays

turn, slowly.

Old weather

says so: after three hours without an update the screen adds "

(old)".

A ringing timer

outranks everything: a reminder can't cover it.

Before anyone tells it the time,

the clock says "waiting for time" instead of guessing.

D E S K T O P - P E T · H A N D B O O K · R E V . 2 | 14

I N S I D E · 1 1

# HOWIT FITS TOGETHER

Aminal never talks to the pet itself. A small bridge program reads what Aminal is doing 25 times a second, and what's playing and what's in front of you once a second, and turns every change into one short line of text. The pet reads those lines, keeps what they say in one shared state it calls the World, and draws that state 50 times a second.

ON THE PC | ON THE DESK

Aminal
state · voice · answers · timers

What's playing, what's in front
the app, its folder, its window title

The speakers

### 16 bars · beats · sudden jumps

Clock and weather
the PC's time · Open-Meteo

Pet bridge
one line per change

ST LV TM
WX TI AL
EM GO MD
VZ BE JS
AC SF CU

heartbeat 2 s
time every 10 min
weather every 20 min

USB cable

always first

WiFi

ESP-01 · port 7676
without the cable

Link
reads USB and WiFi alike

World
time · weather · Aminal · media · activity

Face, screens, cards
eased toward targets every frame

OLED
128 × 64 · about 50 frames a second

ESP-01 WiFi
the link, and its own time and weather

button presses come
back the same way

F I N D I N G T H E P E T

The bridge starts when you log in and runs whether Aminal is open or not. Only one copy ever runs; Aminal starts it if it isn't running, and never stops it.

It only talks to a port that answers HI with PET, so it never sends lines to the wrong

device.

USB always wins. Without the cable it tries WiFi every 15 seconds, at the address the pet gave last time it was plugged in. If that doesn't answer, it searches the home network for the pet's port 7676, at most every 2 minutes.

It sends a heartbeat every 2 seconds. After 8 seconds of silence the pet decides it is on its own and drops any music, code or game face. Over WiFi the bridge drops a pet that hasn't answered for 20 seconds, since a pet that lost its power cord leaves the connection looking open.

The card is handled here too: the pet reports a tap, and the bridge opens or closes the folder.

Nothing is sent twice: each kind of line goes out only when its value changes, apart from the time, which is refreshed every 10 minutes.

# WIRING

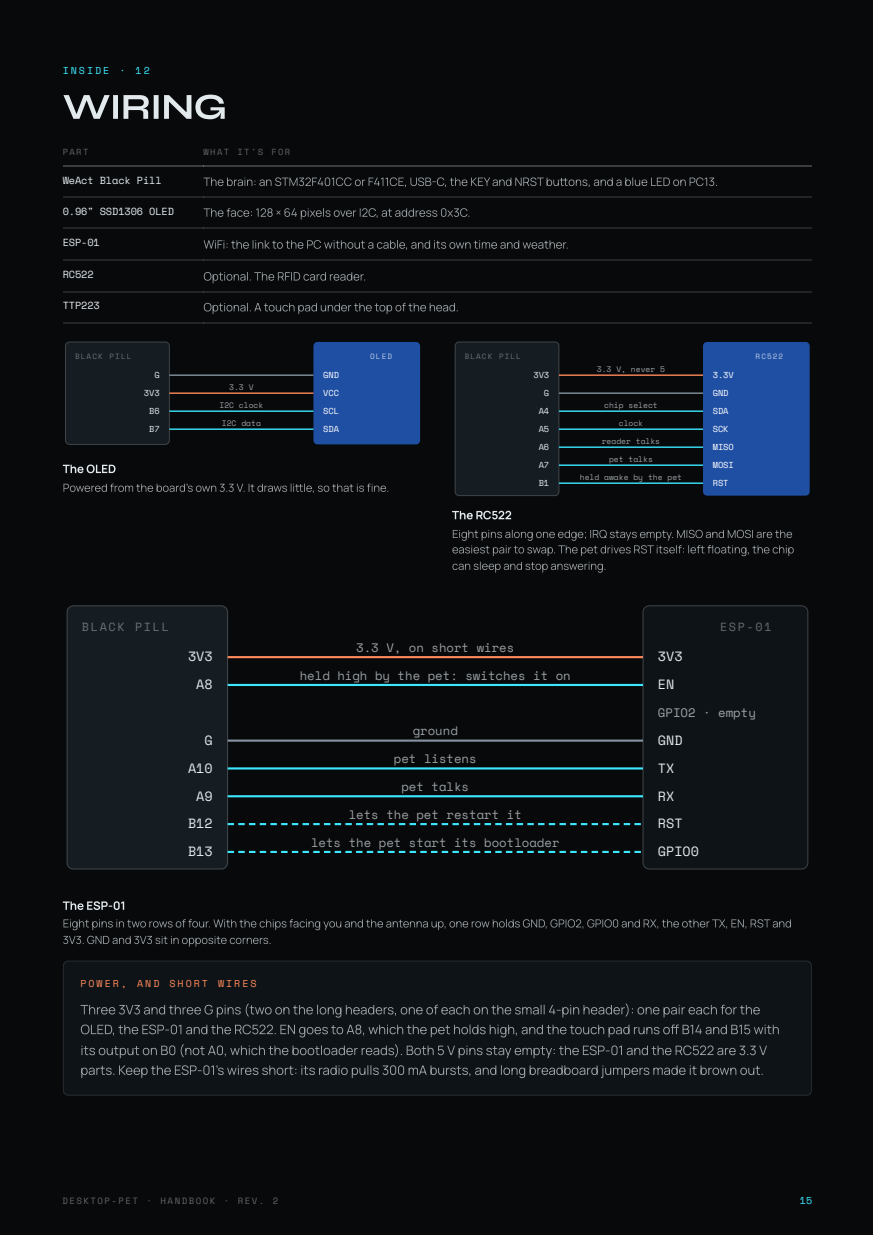
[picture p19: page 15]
WeAct Black Pill; The brain: an STM32F401CC or F411CE, USB-C, the KEY and NRST buttons, and a blue LED on PC13.; 0.96" SSD1306 OLED; The face: 128 × 64 pixels over I2C, at address 0x3C.; ESP-01; WiFi: the link to the PC without a cable, and its own time and weather.; Optional. The RFID card reader.; TTP223; Optional. A touch pad under the top of the head.; BLACK PILL; OLED; GND; VCC; SCL; SDA; I2C clock; I2C data; SCK; MISO; MOSI; RST; 3.3 V, never 5; GPIO0; GPIO2 · empty; ground; pet listens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

chip select
clock
reader talks
pet talks
held awake by the pet

The OLED
Powered from the board's own 3.3 V. It draws little, so that is fine.

The RC522
Eight pins along one edge; IRQ stays empty. MISO and MOSI are the
easiest pair to swap. The pet drives RST itself: left floating, the chip
can sleep and stop answering.

3.3 V, on short wires

held high by the pet: switches it on

lets the pet restart it
lets the pet start its bootloader

The ESP-01
Eight pins in two rows of four. With the chips facing you and the antenna up, one row holds GND, GPIO2, GPIO0 and RX, the other TX, EN, RST and
3V3. GND and 3V3 sit in opposite corners.

Three 3V3 and three G pins (two on the long headers, one of each on the small 4-pin header): one pair each for the
OLED, the ESP-01 and the RC522. EN goes to A8, which the pet holds high, and the touch pad runs off B14 and B15 with
its output on B0 (not A0, which the bootloader reads). Both 5 V pins stay empty: the ESP-01 and the RC522 are 3.3 V
parts. Keep the ESP-01's wires short: its radio pulls 300 mA bursts, and long breadboard jumpers made it brown out.

D E S K T O P - P E T · H A N D B O O K · R E V . 2 | 16

I N S I D E · 1 3

# THE HEAD

A 3D-printable head, 66 × 89.5 × 58 mm: a soft cube with the screen behind a black visor, the Black Pill up on a stand inside, the touch pad under the top and the RFID reader inside the right side. Three parts, printed without supports. The STLfiles, print settings and how to put it together are in the enclosure folder of the repository.

The head
The screen behind the visor.

The right side
Smooth on purpose: nothing shows where the card goes.

Inside the right wall
The RC522, antenna end at the front, its plugs toward the back.

The reader hangs without screws: its top edge in a slot under the roof, its bottom edge in a groove whose inner side slopes at 45°. Tilt it, push the top into the slot, swing the bottom in and let it drop. A card reads through about 6 mm of plastic.

The head was 70 mm deep until the reader went in. The board, its plugs and room for the wires to turn have to fit between the round corners, so the depth is worked out from them.

The Black Pill sits 23.5 mm up, held only by its edges on four springy posts, so every jumper plug hangs free underneath.

The touch pad senses your finger through 1 mm of the top.

# THE FIRMWARE

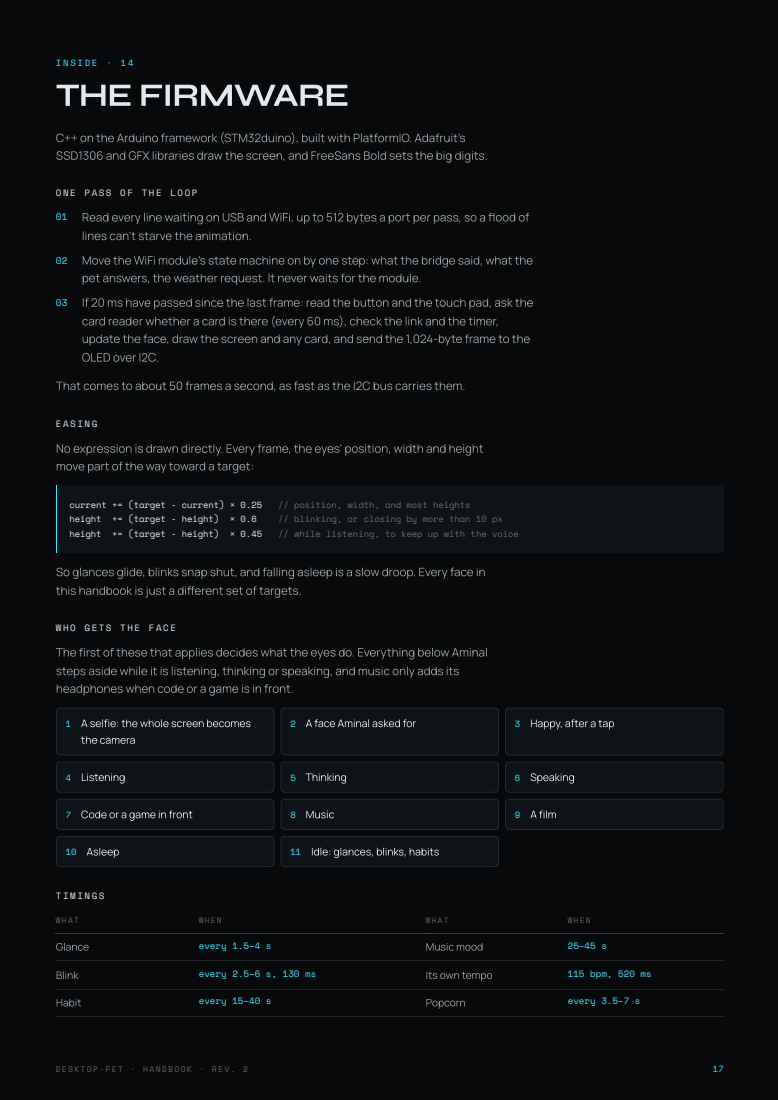
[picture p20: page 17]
current += (target - current) × 0.25; // position, width, and most heights; height += (target - height) × 0.6; // blinking, or closing by more than 10 px; height += (target - height) × 0.45; // while listening, to keep up with the voice; the camera; 2 A face Aminal asked for; 3 Happy, after a tap; 4 Listening; 5 Thinking; 6 Speaking; 7 Code or a game in front; 8 Music; 9 A film; 10 Asleep; 11 Idle: glances, blinks, habits; Glance; every 1.5–4 s; Music mood; Blink; every 2.5–6 s, 130 ms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

C++ on the Arduino framework (STM32duino), built with PlatformIO. Adafruit's
SSD1306 and GFX libraries draw the screen, and FreeSans Bold sets the big digits.

Read every line waiting on USB and WiFi, up to 512 bytes a port per pass, so a flood of
lines can't starve the animation.
Move the WiFi module's state machine on by one step: what the bridge said, what the
pet answers, the weather request. It never waits for the module.
If 20 ms have passed since the last frame: read the button and the touch pad, ask the
card reader whether a card is there (every 60 ms), check the link and the timer,
update the face, draw the screen and any card, and send the 1,024-byte frame to the
OLED over I2C.

That comes to about 50 frames a second, as fast as the I2C bus carries them.

No expression is drawn directly. Every frame, the eyes' position, width and height
move part of the way toward a target:

So glances glide, blinks snap shut, and falling asleep is a slow droop. Every face in
this handbook is just a different set of targets.

The first of these that applies decides what the eyes do. Everything below Aminal
steps aside while it is listening, thinking or speaking, and music only adds its
headphones when code or a game is in front.

1 A selfie: the whole screen becomes

D E S K T O P - P E T · H A N D B O O K · R E V . 2 | 18
W H A T | W H E N | W H A T | W H E N
Happy after a tap | 2.5 s | Back to the face | after 20 s
Hearts | 3 taps under 1.5 s apart | Link lost | 8 s of silence
Falls asleep | 30 s; 10 s, 11 pm–7 am | Hold / double tap | 0.7 s / 0.35 s
Code or a game | 3 s in, 8 s out | Next card tap | after 1.5 s away

Every timer is compared with reached(now, t) rather than now > t, so the pet keeps

blinking when the millisecond counter wraps round after 49.7 days.

D E S K T O P - P E T · H A N D B O O K · R E V . 2 | 19

I N S I D E · 1 5

# THE PROTOCOL

One short line of text per message, the same on USB and WiFi, and simple enough to type into a serial monitor. A line longer than 159 characters is dropped whole rather than read in pieces.

L I N E | M E A N I N G
HI | Who are you? The pet answers PET desktop-pet 11.
PG | Heartbeat, answered PO.
ST idle|listening|thinking|speaking|off | What Aminal is doing
LV 0–100 | How loud the voice is, for the eyes and the mouth
TM <unix> <offset s> | The time, and the UTC offset
WX <temp> <code> <hi> <lo> <place> | The weather, with its WMO code
TI <left> <total> <paused> <label> | The timer, or TI - for none
AL <secs> <title>|<text> | A card, or AL - to take it down
EM <face> [ms] | Pull a face: happy, love, surprised, sad, angry, wink, sleepy
GO <screen> [secs] | Show face, clock, weather, timer, usage or status
CU <session %> <reset> <week %> <reset> | Claude's usage, each reset as Unix time
MD music [style] | watch | - | What's playing. A music style (headphones, dance, bars) can be asked for by name.
VZ <16 hex digits> | Spectrum bars, 0 to f each, low notes first
BE | A beat
JS | A sudden loud moment in a film or a game
AC code [typing] | game | - | What's in front on the PC
SF ready | count <ms> | shot | - | A selfie: the camera opening, the spoken countdown, the shutter, done
SN | Answered SN <hex>: exactly what is on the OLED
IP | Answered IP <address> or IP -: where it is on WiFi
RF, RF test, RF poll | The card reader: its chip version, a wiring test, one try at reading a card
LO <lat> <lon> <place> | Where the weather is for, kept in flash for the WiFi
WF <ssid><tab><password> | USB only: join a WiFi network
ES talk|flash [baud], ES reset | USB only: the cable straight through to the ESP-01, for debugging

The pet sends events back up whichever link spoke last: EV pet, EV next <screen>,

### EV hold, EV hold timer, EV dismiss, EV wifi ok <ip>, EV wifi fail and EV card

<uid> tap.

D E S K T O P - P E T · H A N D B O O K · R E V . 2 | 20

A F E W S E C O N D S O F C O N V E R S A T I O N

→ HI
← PET desktop-pet 11
→ TM 1790658725 19800 | // 10:42 on 29 Sep, India's +5:30
→ WX 29 2 32 24 Mumbai
→ ST listening
→ LV 64
→ ST speaking
→ MD music dance
→ BE
→ AC code typing | // VS Code in front, keys going
← EV pet | // someone tapped it

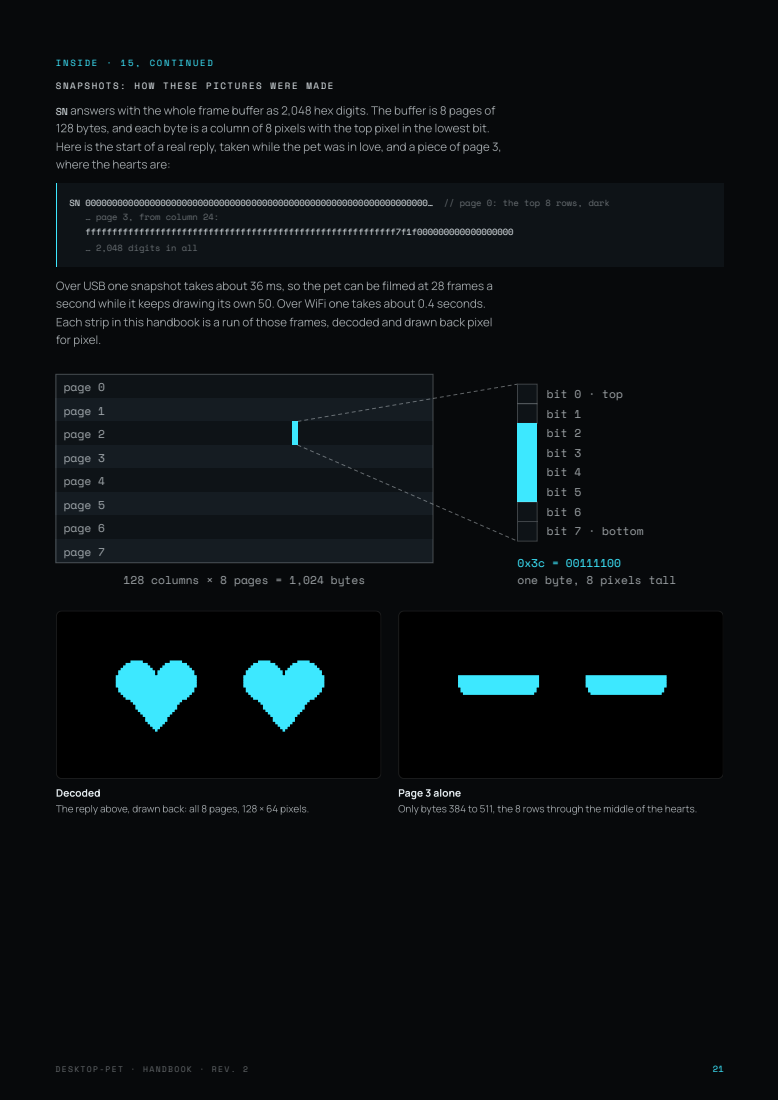
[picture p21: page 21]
page 0; page 1; page 2; page 3; page 4; page 5; page 6; page 7; bit 0 · top bit 1 bit 2 bit 3 bit 4 bit 5 bit 6 bit 7 · bottom

SN answers with the whole frame buffer as 2,048 hex digits. The buffer is 8 pages of
128 bytes, and each byte is a column of 8 pixels with the top pixel in the lowest bit.
Here is the start of a real reply, taken while the pet was in love, and a piece of page 3,
where the hearts are:

SN 0000000000000000000000000000000000000000000000000000000000000000… // page 0: the top 8 rows, dark
… page 3, from column 24:
ffffffffffffffffffffffffffffffffffffffffffffffffffffffffff7f1f000000000000000000
… 2,048 digits in all

Over USB one snapshot takes about 36 ms, so the pet can be filmed at 28 frames a
second while it keeps drawing its own 50. Over WiFi one takes about 0.4 seconds.
Each strip in this handbook is a run of those frames, decoded and drawn back pixel
for pixel.

one byte, 8 pixels tall

128 columns × 8 pages = 1,024 bytes

Page 3 alone
Only bytes 384 to 511, the 8 rows through the middle of the hearts.

Decoded
The reply above, drawn back: all 8 pages, 128 × 64 pixels.

D E S K T O P - P E T · H A N D B O O K · R E V . 2 | 22

I N S I D E · 1 6

# HOWIT HEARS MUSIC

All of this runs on the PC, inside the bridge. The pet only ever receives the results as MD, VZ, BE and JS lines.

S T E P | W H A T H A P P E N S

1 · What's playing Once a second, Windows' per-app volume meters list the apps making sound (a peak above 2%). Each is named by

| its app, then its window title, then the file it plays. The loudest one that gets a name wins.
2 · Listening in | Only while music or a film is on, or a game is in front, the bridge records what the speakers play through WASAPI loopback (PyAudioWPatch).
3 · Bars | Each block of 1,024 samples, about 23 ms, goes through an FFT into 16 bands spaced by pitch from 50 Hz to 12 kHz. The top end is lifted 4.5 dB per octave so the treble moves as much as the bass, and the bars show the loudest 40 dB under an automatic gain. Sent as VZ 20 times a second.
4 · Beats | Energy between 40 and 150 Hz rising to 1.45 times its average over the last second, at least 0.28 s after the last beat. Sent as BE.
5 · Jumps | A block 4 times louder than the median of the last 5 seconds, at most once every 8 seconds. Sent as JS, for films and games.

T H E S O U N D S T A Y S P U T

Each block becomes 16 numbers and two yes-or-no flags and is thrown away. Nothing is recorded, saved or sent anywhere, and the listener only runs while the pet has music, a film or a game to show.

N A M E D F O R C E R T A I N , O R N O T A T A L L

C L U E | M U S I C | F I L M
The app | Spotify, Apple Music, Tidal, Deezer, foobar2000, MusicBee… | Netflix, Prime Video, Disney+, Hotstar, JioCinema apps
A browser's title | Spotify, YouTube Music, SoundCloud, JioSaavn,

Gaana, Wynk

Netflix, Prime Video, Hotstar, JioCinema, Disney+, SonyLIV, ZEE5, Apple TV

A video player's file .mp3, .flac, .m4a, .wav, .ogg, .opus, .aac, .wma | anything else it plays

Browsers are recognised even when they aren't on the list, by the audio helper
process every Chromium and Firefox browser uses. That is how Comet was picked
up.

D E S K T O P - P E T · H A N D B O O K · R E V . 2 | 23

I N S I D E · 1 7

# WIFI

The ESP-01 keeps the factory AT firmware it shipped with, and the pet drives it with plain text commands. Once it has joined a network it makes one plain HTTP request to Open-Meteo every 20 minutes. That single reply carries the time (in its Date header), the UTC offset and today's weather, so a pet on a charger keeps its clock and forecast with the PC switched off.

It also listens on port 7676, and whoever connects there, the bridge on the PC when the pet has only a power cord, speaks the same protocol as USB. The module's multi-link mode makes that possible: the weather request goes out on link 4 while the bridge comes in on another. While the bridge is connected it brings the time and
weather itself, so the pet skips its own request.

start → reset → ATE0 → AT+CWMODE_DEF? → AT+CIPMUX=1 → AT+CIPSERVER=1,7676 → AT+CIFSR → idle idle → AT+CIPSTART=4,"TCP","api.open-meteo.com",80 → AT+CIPSEND=4,… → GET → +IPD,4,… → 4,CLOSED // every 20 min while no bridge is connected; again after 5 min if it failed
idle ↔ +IPD,0,… in from the bridge, AT+CIPSEND=0,… back to it

J O I N I N G

Run the bridge's WiFi setup with the pet on USB. It offers the network the PC is on, asks for the password without showing it, and sends both down the USB cable only: the pet refuses them over WiFi. The module remembers the network and rejoins by itself. It only sees 2.4 GHz networks.

W H A T I T K E E P S

Where the weather is for (sent by Aminal as LO) and the

UTC offset are saved in the last sector of the Black Pill's flash, so they survive a power cut. The WiFi password isn't: only the module holds it.

A C L E A N S T A R T

The pet resets the module at every power-up, and again whenever it stops answering, so a bad power-up can't leave the WiFi stuck. Anyone on the same network can reach port 7676 too, so it's meant for a home network; joining a network and the passthrough to the module stay USB only.

D E S K T O P - P E T · H A N D B O O K · R E V . 2 | 24

I N S I D E · 1 8

# BUILDING AND UPLOADING

WeAct boards ship with the WeAct HID bootloader in their first 16 KB. Windows sees it
as a plain HID device (0483:572A), so it needs no driver, and it avoids the chip's own

USB bootloader, which often fails with Device Descriptor Request Failed.

The default build targets the F401CC and also runs on an F411CE. For the F411's full 100 MHz, check the square chip and switch default_envs to blackpill_f411ce.

W H E R E E V E R Y T H I N G L I V E S I N F L A S H

HID bootloader | Desktop-pet, 104 KB | 8 KB | last sector: the saved place and offset
16 KB | | | 128 KB sector, nearly empty

0x08000000
0x08004000
0x08020000 | 0x08040000

That is the F401CC's 256 KB, drawn to scale. The app is linked to start right after the bootloader, at 0x08004000, and has about 8 KB of room before it would meet the saved settings. The build refuses to grow past them: PlatformIO is told where flash ends for the app.

Install PlatformIO. In VS Code, open Extensions, search for PlatformIO IDE and install it.

01

Get the uploader. Download WeAct_HID_Flash-CLI.exe from WeAct's repository and save it as tools/WeAct_HID_Flash-CLI.exe. It is WeAct's own closed tool, so it isn't in

the repository.

02

Open the project. File, Open Folder, Desktop-pet. PlatformIO fetches the STM32

toolchain and the display libraries itself.

03

Enter the bootloader. Hold KEY, tap NRST, wait for the blue LED to blink, then let go of KEY. A brand new board is already in it.

04

05 Upload. Click the arrow in the blue status bar.

06 Wake it. The eyes appear. If they don't, tap NRST.

D E S K T O P - P E T · H A N D B O O K · R E V . 2 | 25

I N S I D E · 1 9

# WHEN SOMETHING'S OFF

W H A T Y O U S E E | L I K E L Y C A U S E

Blue LED blinking fast,

screen blank

The OLED isn't answering on I2C. Check its four wires, then try address 0x3D in src/main.cpp.

Upload can't find the board It isn't in the bootloader. Hold KEY, tap NRST, let go when the LED blinks.

No HID device at all, even

holding KEY

The bootloader was erased by a DFU or ST-Link upload to 0x08000000. Reflash it from WeAct's repository, or build without the flash offset.

Garbage on the screen | The module may be an SH1106, common on 1.3 inch boards, which needs a different library.

The pet never follows the

PC

The status screen says Link none: the bridge isn't running (it starts at login), or something else has the port.

ESP-01 answers AT, then

garbles and restarts

A brownout, usually from long jumper wires. Use short direct ones (chapter 12).

The card does nothing | Send RF test over USB. A value written to the reader should read back the same, rw 5a/5a a5/a5. If every

read is the same number, a wire to the RC522 is wrong or loose; check SDA, SCK and RST first.

A M A P O F T H E C O D E

F I L E | W H A T ' S I N I T
src/pet.h | The shared World: time, weather, timer, Aminal's state, media, what's in front, a selfie, the current card
src/main.cpp | Setup, the frame loop, the button, switching screens
src/face.cpp | Eyes, moods, habits, and the listening, thinking, speaking, music and film faces
src/media.cpp | Headphones, music notes, the visualizer and the popcorn
src/activity.cpp | Glasses, the keyboard and paws, the controller and the sparks
src/camera.cpp | The camera face for a selfie: countdown, flash and shutter
src/rfid.cpp | The card reader, and turning a card's arrival into a tap
src/screens.cpp | Clock, weather icons, timer, Claude's usage, status and the cards
src/link.cpp | The protocol, read from USB and WiFi alike, and the ESP-01 passthrough
src/wifi.cpp | The ESP-01 driven through its AT firmware: joining, the weather request, and the bridge's link on port 7676

D O C U M E N T H I S T O R Y

R E V I S I O N D A T E | W H A T C H A N G E D
Rev. 2 | 2 Oct 2026 For firmware v11: coding and gaming faces, the selfie camera, the RFID card, a page for Claude's usage, WiFi as

the link to the PC, a bridge that runs without Aminal, Bluetooth taken out, new wiring for the ESP-01, the RC522 and the touch pad, and a chapter on the printed head.

Rev. 1 | 29 Sep 2026 First edition, for firmware v6: the user guide, the technical notes, and real captures of every face and screen.
DESKTOP-PET · BY MOSAM BISWAS | GITHUB.COM/BISWASMOSAM/DESKTOP-PET

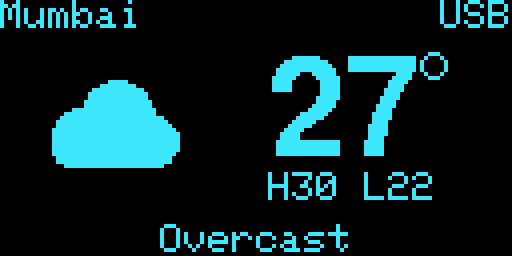
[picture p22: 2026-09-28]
docs/shots/wx_fog.gif

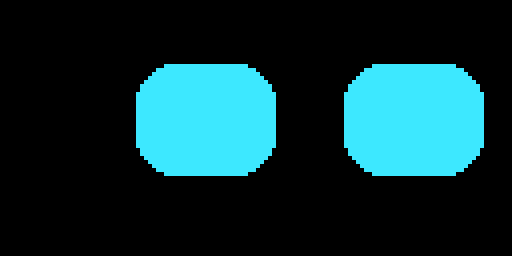
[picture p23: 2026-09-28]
docs/shots/card.gif

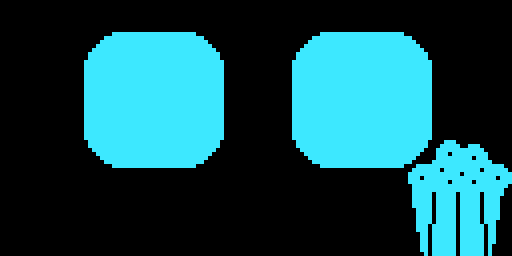
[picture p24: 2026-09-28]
docs/shots/watch.gif

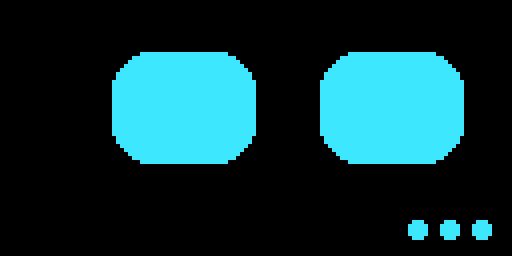
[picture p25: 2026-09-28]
docs/shots/thinking.gif

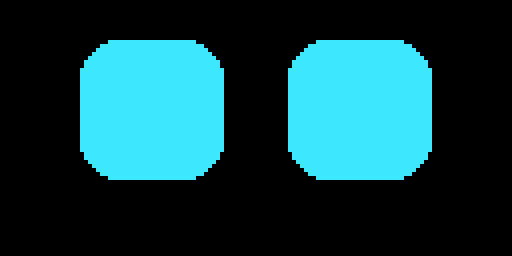
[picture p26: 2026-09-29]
enclosure/renders/face.png

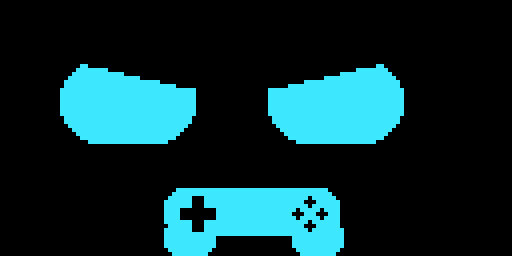
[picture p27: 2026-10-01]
docs/shots/game.gif

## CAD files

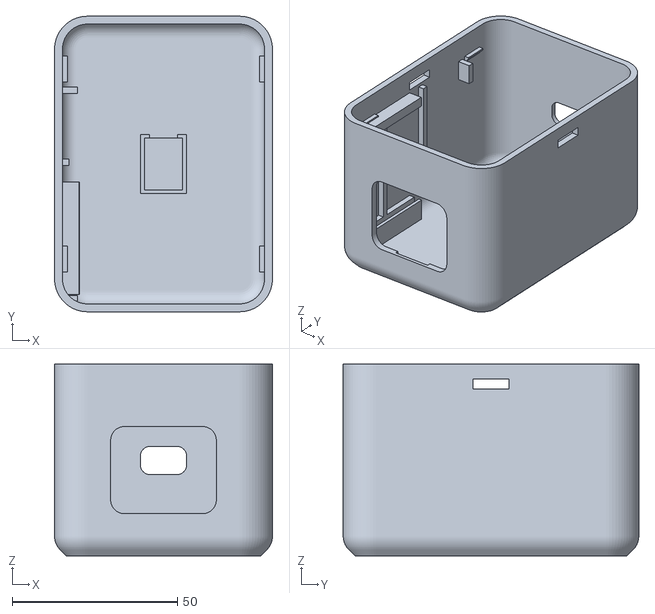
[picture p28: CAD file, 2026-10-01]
enclosure/stl/shell.stl
66.0 x 89.5 x 58.0

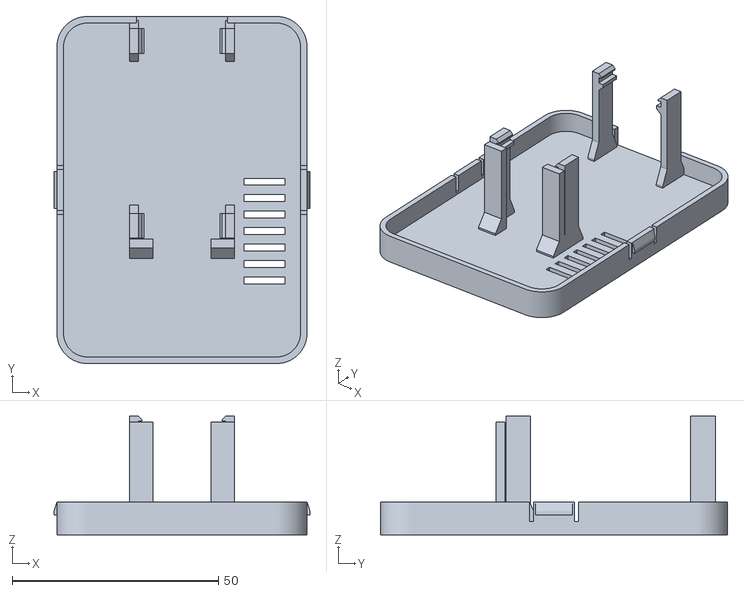
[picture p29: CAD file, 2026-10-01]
enclosure/stl/base.stl
62.1 x 84.2 x 28.8

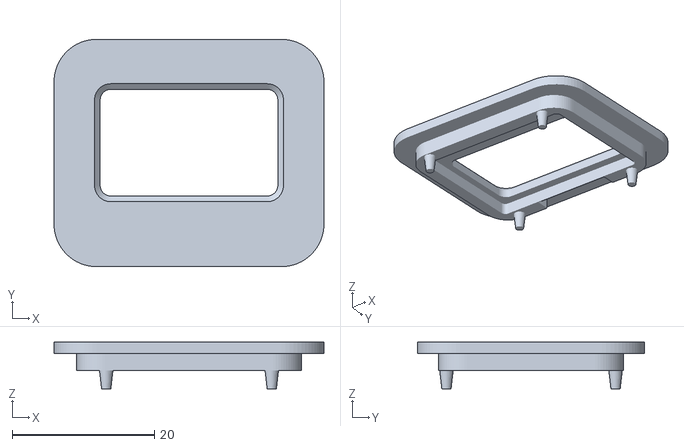
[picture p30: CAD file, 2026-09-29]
enclosure/stl/visor.stl
38.0 x 32.0 x 6.60

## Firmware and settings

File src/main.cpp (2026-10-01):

// Desktop pet: a face on the desk that keeps Aminal company.
// Black Pill + 0.96" SSD1306 OLED (SCL -> B6, SDA -> B7, VCC -> 3V3, GND -> GND).
// HC-05 Bluetooth (optional): TXD -> A3, RXD -> A2, VCC -> 5V, GND -> GND.
//
// KEY (PA0) is the only button, or a TTP223 touch pad on B0 under the top of
// the enclosure, which does exactly the same:
//   tap         pet it (on the face), next screen (anywhere else), dismiss a card
//   double tap  next screen
//   hold        back to the face; on the timer, pause or resume it

#include <Wire.h>
#include "pet.h"

#define OLED_ADDR  0x3C   // some modules use 0x3D
#define LED_PIN    PC13   // onboard LED, on when LOW
#define KEY_PIN    PA0    // onboard KEY button, LOW when pressed
#define TOUCH_PIN  PB0    // TTP223 touch pad (optional), HIGH while touched.
#define TOUCH_VCC  PB14   // and its power: it draws a few microamps, so two
#define TOUCH_GND  PB15   // pins feed it and the 3V3/G pins go further
                          // Not PA0: the bootloader reads PA0 at reset, and a
                          // TTP223 holds its output LOW when nobody's touching.

Adafruit_SSD1306 display(SCREEN_W, SCREEN_H, &Wire, -1);
World world;
Screen screen = SCR_FACE;

const uint32_t BROWSE_MS    = 20000;  // a screen you flipped to returns to the face after this
const uint32_t DOUBLE_TAP_MS = 350;
const uint32_t HOLD_MS      = 700;

static uint32_t screenUntil = 0;      // 0 = stay put
static uint32_t lastFrame = 0;

// ---------- Clock and timer ----------

bool clockNow(struct tm &out) {
  if (!world.timeValid) return false;
  time_t t = (time_t)world.epochAtSync + (millis() - world.millisAtSync) / 1000
           + world.tzOffset;
  gmtime_r(&t, &out);
  return true;
}

uint32_t timerLeftMs(uint32_t now) {
  if (!world.timerOn) return 0;
  if (world.timerPaused) return world.timerLeftMs;
  uint32_t gone = now - world.timerSyncMs;
  return gone >= world.timerLeftMs ? 0 : world.timerLeftMs - gone;
}

// ---------- Screens ----------

const char *screenName(Screen s) {
  static const char *NAMES[] = {"face", "clock", "weather", "timer", "usage", "status"};
  return s < SCR_COUNT ? NAMES[s] : "";
}

void goScreen(Screen s, uint32_t holdMs, uint32_t now) {
  screen = s;
  screenUntil = (s == SCR_FACE || holdMs == 0) ? 0 : now + holdMs;
  faceWake(now);
}

static void nextScreen(uint32_t now) {
  // The timer only while one runs, Claude's usage only once it has been heard
  Screen s = screen;
  do s = (Screen)((s + 1) % SCR_COUNT);
  while ((s == SCR_TIMER && !world.timerOn) || (s == SCR_USAGE && !world.cuValid));
  goScreen(s, BROWSE_MS, now);

  char ev[24];
  snprintf(ev, sizeof(ev), "EV next %s", screenName(s));
  linkEvent(ev);
}

// ---------- The button ----------

static bool keyDown = false, holdFired = false;
static uint32_t downAt = 0, lastTapAt = 0;

static void onTap(uint32_t now) {
  if (world.alertOn) {
    if (world.alertLoud) linkEvent("EV dismiss");
    dismissAlert();
  } else if (screen == SCR_FACE) {
    faceTouch(now);
    linkEvent("EV pet");
  } else {
    nextScreen(now);
  }
}

static void onHold(uint32_t now) {
  if (screen == SCR_TIMER && world.timerOn) {
    linkEvent("EV hold timer");       // Aminal pauses or resumes it
  } else {
    goScreen(SCR_FACE, 0, now);
    linkEvent("EV hold");
  }
}

static void handleKey(uint32_t now) {
  bool pressed = digitalRead(KEY_PIN) == LOW || digitalRead(TOUCH_PIN) == HIGH;
  if (pressed && !keyDown) {
    keyDown = true;
    holdFired = false;
    downAt = now;
  } else if (pressed && !holdFired && now - downAt >= HOLD_MS) {
    holdFired = true;
    onHold(now);
  } else if (!pressed && keyDown) {
    keyDown = false;
    if (holdFired) return;
    // The first tap acts at once, so petting never lags. A quick second tap
    // on the face also flips to the next screen.
    bool second = lastTapAt && now - lastTapAt < DOUBLE_TAP_MS;
    lastTapAt = second ? 0 : now;
    if (second && screen == SCR_FACE && !world.alertOn) nextScreen(now);
    else onTap(now);
  }
}

// ---------- Setup and loop ----------

void setup() {
  pinMode(KEY_PIN, INPUT_PULLUP);
  pinMode(TOUCH_PIN, INPUT_PULLDOWN);   // reads "not touched" with no pad fitted
  pinMode(TOUCH_VCC, OUTPUT);
  digitalWrite(TOUCH_VCC, HIGH);
  pinMode(TOUCH_GND, OUTPUT);
  digitalWrite(TOUCH_GND, LOW);
  pinMode(LED_PIN, OUTPUT);
  digitalWrite(LED_PIN, HIGH);  // LED off

  linkBegin();
  wifiBegin();
  rfidBegin();

  Wire.setSDA(PB7);
  Wire.setSCL(PB6);
  Wire.begin();

  if (!display.begin(SSD1306_SWITCHCAPVCC, OLED_ADDR)) {
    // OLED not found: fast-blink the onboard LED forever
    bool on = false;
    while (true) {
      on = !on;
      digitalWrite(LED_PIN, on ? LOW : HIGH);
      delay(100);
    }
  }

  randomSeed(analogRead(PA1));
  faceBegin(millis());

  display.clearDisplay();
  display.display();
}

void loop() {
  uint32_t now = millis();
  linkPoll(now);                      // every pass, so lines never pile up
  wifiTick(now);
  if (now - lastFrame < 20) return;   // about 50 fps, as the I2C allows
  lastFrame = now;

  handleKey(now);
  rfidTick(now);
  linkTick(now);
  if (screenUntil && reached(now, screenUntil)) goScreen(SCR_FACE, 0, now);
  if (world.alertOn && reached(now, world.alertUntil)) dismissAlert();
  faceUpdate(now);

  display.clearDisplay();
  switch (screen) {
    case SCR_CLOCK:   drawClock(now);   break;
    case SCR_WEATHER: drawWeather(now); break;
    case SCR_TIMER:   drawTimer(now);   break;
    case SCR_USAGE:   drawUsage(now);   break;
    case SCR_STATUS:  drawStatus(now);  break;
    default:          faceDraw(now);    break;
  }
  if (world.alertOn) drawAlert(now);
  display.display();
}

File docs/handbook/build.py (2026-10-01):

"""Build the handbook twice from handbook.src.html:

  site/index.html   the web page: animated GIFs, Google Fonts
  paper.html        the PDF source: frame strips, local fonts, A4 pages

Every screen image is a real frame-buffer capture from shots/*.npz, drawn
as vector pixels (or, on the web, the GIF made from the same capture).
"""
import html
import re

import numpy as np

FONT_C = "D:/Garage/Desktop-pet/.pio/libdeps/blackpill_f401cc/Adafruit GFX Library/glcdfont.c"

WEB_FONTS = ('<link rel="preconnect" href="https://fonts.googleapis.com">'
             '<link rel="preconnect" href="https://fonts.gstatic.com" crossorigin>'
             '<link rel="stylesheet" href="https://fonts.googleapis.com/css2?'
             'family=Manrope:wght@400;500;600;700&family=Space+Mono&family=Syne:wght@600;700;800&display=swap">')

LOCAL = "file:///D:/Garage/BiswasMosam.github.io/fonts/"
MONO_RANGE = ("U+0000-003F, U+0041-00FF, U+0131, U+0152-0153, U+02BB-02BC, U+02C6, "
              "U+02DA, U+02DC, U+2000-206F, U+20AC, U+2122, U+2191, U+2193, U+2212, "
              "U+2215, U+FEFF, U+FFFD")
PAPER_FONTS = "<style>" + "".join(
    f"@font-face{{font-family:'{fam}';font-weight:{w};font-style:normal;"
    f"src:url('{LOCAL}{file}') format('woff2'){rng}}}"
    for fam, w, file, rng in [
        ("Syne", 600, "syne-600-latin.woff2", ""),
        ("Syne", 700, "syne-700-latin.woff2", ""),
        ("Syne", 800, "syne-800-latin.woff2", ""),
        ("Manrope", 400, "manrope-400-latin.woff2", ""),
        ("Manrope", 500, "manrope-500-latin.woff2", ""),
        ("Manrope", 600, "manrope-600-latin.woff2", ""),
        ("Manrope", 700, "manrope-600-latin.woff2", ""),
        ("Space Mono", 400, "space-mono-400-latin.woff2", f";unicode-range:{MONO_RANGE}"),
    ]) + "</style>"


# ---------------------------------------------------------------- captures

_cache = {}


def load(name):
    if name not in _cache:
        d = np.load(f"shots/{name}.npz")
        _cache[name] = (d["t"], d["frames"])
    return _cache[name]


def pick(name, spec):
    """Frame indices from '12,69' or times '2.4s,3s'; -1 is the last frame."""
    t, F = load(name)
    out = []
    for s in spec.split(","):
        s = s.strip()
        if s.endswith("s"):
            out.append(int(np.argmin(np.abs(t - float(s[:-1])))))
        else:
            i = int(s)
            out.append(i if i >= 0 else len(F) + i)
    return out


def oled_svg(frame, label):
    """One frame as vector pixels: a run per row, overlapped a hair so no
    seams show between rows in a PDF viewer."""
    runs = []
    for y in range(64):
        row = frame[y]
        x = 0
        while x < 128:
            if row[x]:
                x0 = x
                while x < 128 and row[x]:
                    x += 1
                runs.append(f"M{x0} {y}h{x - x0 + .03:g}v1.04h-{x - x0 + .03:g}z")
            else:
                x += 1
    return (f'<svg viewBox="0 0 128 64" role="img" aria-label="{html.escape(label)}" '
            f'preserveAspectRatio="xMidYMid meet"><rect width="128" height="64" class="px-off"/>'
            f'<path class="px-on" d="{"".join(runs)}"/></svg>')


# ---------------------------------------------------------------- 5x7 font

def glcd_font():
    src = open(FONT_C, encoding="utf-8").read()
    body = src[src.index("font[] PROGMEM = {") :]
    body = body[: body.index("};")]
    return [int(b, 16) for b in re.findall(r"0x[0-9A-Fa-f]{2}", body)]


FONT = glcd_font()


def pixel_text(text, cls="wordmark", dot=0.84, label=None):
    """Text in the pet's own 5x7 font, each pixel a rounded dot."""
    cells = []
    for i, ch in enumerate(text):
        base = ord(ch) * 5
        for col in range(5):
            bits = FONT[base + col]
            for row in range(8):
                if bits >> row & 1:
                    x, y = i * 6 + col, row
                    cells.append(f'<rect x="{x + (1 - dot) / 2:g}" y="{y + (1 - dot) / 2:g}" '
                                 f'width="{dot}" height="{dot}" rx="{dot * .22:.3f}"/>')
    w = len(text) * 6 - 1
    return (f'<svg class="{cls}" viewBox="0 0 {w} 8" role="img" '
            f'aria-label="{html.escape(label or text)}">{"".join(cells)}</svg>')


# ---------------------------------------------------------------- figures

def figure(target, spec):
    """<!--FIG name | frames | title | caption | options-->"""
    parts = [p.strip() for p in spec.split("|")]
    name, frames, title, caption = parts[:4]
    opts = dict(o.split("=", 1) if "=" in o else (o, "1")
                for o in (parts[4].split() if len(parts) > 4 else []))
    t, F = load(name)
    idx = pick(name, frames)
    cls = "fig" + (" " + opts["class"] if "class" in opts else "")
    cap = f'<figcaption><b>{title}</b> {caption}</figcaption>'
    invert = float(opts.get("invert", 0))

    def frame(i):
        f = F[i]
        if "rows" in opts:
            lo, hi = map(int, opts["rows"].split("-"))
            f = f.copy()
            f[:lo] = 0
            f[hi + 1:] = 0
        if invert and int(t[i] / invert) % 2 == 1:
            f = f ^ 1
        return f

    if target == "web":
        gif = opts.get("gif", name if len(idx) > 1 else "")
        if gif:
            lazy = "" if "bare" in opts else ' loading="lazy"'
            art = (f'<img src="shots/{gif}.gif" alt="{html.escape(title)}: real capture" '
                   f'width="512" height="256"{lazy}>')
        else:
            art = oled_svg(frame(idx[-1] if len(idx) > 1 else idx[0]), title)
        if "bare" in opts:
            return art
        return f'<figure class="{cls}"><div class="oled">{art}</div>{cap}</figure>'

    if "bare" in opts:
        return oled_svg(frame(idx[0]), title)

    if len(idx) == 1:
        return f'<figure class="{cls}"><div class="oled">{oled_svg(frame(idx[0]), title)}</div>{cap}</figure>'
    t0 = t[idx[0]]
    cells = "".join(
        f'<div class="cell"><div class="oled">{oled_svg(frame(i), title)}</div>'
        f'<span class="tc">{t[i] - t0:.2f} s</span></div>' for i in idx)
    return (f'<figure class="{cls} film" style="--n:{len(idx)}">'
            f'<div class="frames">{cells}</div>{cap}</figure>')


def listen_frames():
    """Listening, quiet to loud: the smallest, a middling and the biggest open eyes."""
    t, F = load("listening")
    heights = [int(np.ptp(np.nonzero(f)[0]) + 1) if f.any() else 0 for f in F]
    cand = sorted((h, i) for i, h in enumerate(heights) if t[i] > 0.3 and h >= 30)
    lo, hi = cand[0], cand[-1]
    mid = min(cand, key=lambda c: abs(c[0] - (lo[0] + hi[0]) / 2))
    return ",".join(str(i) for i in sorted({lo[1], mid[1], hi[1]}))    # in time order
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

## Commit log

2026-09-28 Desktop pet step 1: the face
    Animated eyes on a 0.96" SSD1306 OLED driven by an STM32 Black Pill.
    Glances and blinks when idle, turns happy when KEY is pressed, falls
    asleep after 30 s alone. Builds for both F401CC and F411CE over DFU.
    Timers survive the millis() wrap, the happy cutout no longer swallows
    a half-open eye waking from sleep, and Serial runs over USB CDC.
    [main.cpp]
2026-09-28 Upload through the WeAct HID bootloader the board ships with
    The Black Pill came with WeAct's HID bootloader (0483:572A) in the first
    16 KB of flash, while the chip's own DFU bootloader kept failing with
    Device Descriptor Request Failed. Link the app at 0x08004000 and upload
    with WeAct_HID_Flash-CLI instead: no Zadig, no driver, no BOOT0 dance.
2026-09-28 Aminal's face on the desk: states, clock, weather, timer, cards
    The pet now speaks a one-line text protocol over USB and the HC-05 alike
    (HI, ST, LV, TM, WX, TI, AL, EM, GO, SN) and becomes the physical face
    of Aminal: eyes wide while it listens, looking up while it thinks, and a
    mouth that opens with its voice while it speaks. Alone it is still a
    pet, now with fidgets, love hearts after three taps, and a small clock
    while it sleeps.
    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
2026-09-28 A bell for Time's up, AL - to clear a card, Bluetooth notes
    The ringing timer now takes the whole screen: a bell swinging side to
    side, the title in big type, and the screen flashing, instead of a card
    that was mostly empty space. AL - lets Aminal take a card down. README
    gains how the HC-05 was actually paired: Windows 11 lists it as Unknown
    device until the old DevicePairingWizard is used, and a dark LED was a
    loose VCC wire.
2026-09-28 Music and films: headphones, dancing, a visualizer, and popcorn
    MD music|watch|- from Aminal puts the pet in a mood. Music gets one of
    three at random, rerolled every 25-45 s: headphones on and eyes shut,
    nodding on each beat; dancing side to side with notes floating up; or a
    full-screen 16-bar visualizer of the real spectrum (VZ) with falling peak
    marks. Beats (BE) come from Aminal's loopback, with a 115 bpm fallback.
    A film gets eyes up at the screen, a striped popcorn bucket, a kernel
    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
2026-09-28 The WiFi module's own firmware (ESP-01, not flashed yet)
    esp01/ is a separate PlatformIO project for the ESP8266 on USART1. It
    speaks the pet's protocol: NW for its WiFi state, TM from NTP, WX from
    Open-Meteo over HTTPS for the place Aminal sends as LO (kept in flash,
    with the UTC offset Open-Meteo reports). With no network saved it opens
    a "Desktop-pet" access point for setup from a phone (WiFiManager). A
    TCP client on desktop-pet.local:7676 is relayed to the pet a whole line
    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
2026-09-28 README: the ESP-01 needs its own 3.3 V regulator
    Measured on this board: it answers AT fine, but while joining or scanning
    its serial turns to garbage and it crashes, even at reduced RF power. The
    Black Pill's regulator can't deliver the radio's ~300 mA bursts.
2026-09-28 Timer: "paused" sits beside the link name instead of on top of it
2026-09-28 The handbook: a user guide and technical notes, with real captures
    A 19-page PDF (docs/Desktop-pet-Handbook.pdf) covering every face, trick
    and screen, the wiring, the firmware, the protocol, how it hears music and
    WiFi. Every picture is a frame-buffer capture taken over USB with SN; the
    captures and the build that turns them into the PDF and its web edition
    are in docs/handbook. The README shows three of them and links the PDF.
2026-09-29 A 3D-printable head, and a touch pad to pet it by
    enclosure/: a soft cube with ears, the OLED clamped behind a black visor,
    the Black Pill clicked into a cradle lined up with a USB-C port in the
    back, and a pocket for a TTP223 under the thinned top. Four parts, all in
    print orientation, none needing supports. model.py builds them from named
    dimensions, check.py fits them together with stand-ins for the boards and
    a USB-C plug (no overlaps), render.mjs draws the pictures.
    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
    [base.stl, ears_cat.stl, ears_round.stl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]
2026-09-29 Enclosure: no ears, and the Black Pill up on a stand
    The Black Pill is wired with its headers pointing down, so every jumper
    plug hangs underneath. The base now carries it 23.5 mm up on a spine
    between the two rows of plugs, with a shoulder that takes the push of the
    USB cable and four springy posts that clip over its edges; the plugs end
    7 mm above the floor. The USB-C port moves up to match. check.py puts a
    plug on all 40 pins: no overlaps. The ears and their sockets are gone.
    [base.stl, ears_cat.stl, ears_round.stl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]
2026-09-29 Enclosure: hold the Black Pill by its edges, clear of the SWD header
    Its 4-pin SWD header is on the underside, in the middle of the far end,
    right where the spine and its end stop were. The base now holds the board
    at four points on its edges: a ledge under each (in the strip outside the
    header strips) and a clip over it, the front two wrapping round the
    corners to take the USB cable's push. Nothing is under the board between
    the header strips. check.py adds the SWD header, straight with a plug or
    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
    [base.stl]
2026-10-01 Coding and gaming: glasses and typing paws, a controller and sparks
    AC code [typing] | game | - says what's in front on the PC. Music on top
    adds the headphones instead of taking over. The link going quiet now
    clears the media and the activity, so a pulled cable doesn't leave the
    pet dancing or typing forever. Protocol 7.
    [link.cpp, pet.h]
2026-10-01 The bridge over WiFi: the ESP-01 serves the protocol on port 7676
    With only a power cord on the pet, the PC still reaches it. The factory AT
    firmware runs in multi-link mode: the weather request on link 4, a server
    on 7676 for the bridge, which becomes a third port beside USB and the
    HC-05. IP answers the pet's address so the bridge can find it later. The
    module is reset at every boot and when it stops answering, so a bad
    power-up can't leave the WiFi stuck. Also: code symbols fly out under the
    glasses, not into them, and a link gone quiet clears music and activity.
    Protocol 8.
    [link.cpp, pet.h, wifi.cpp]
2026-10-01 A camera face for Aminal's selfie: countdown, flash and shutter
    SF ready / count <ms> / shot / - drive it. The lens focuses while the
    webcam opens, 3-2-1 lands inside it with the spoken words (placed at
    where Piper says them), and the flash and shutter blink go off on SF
    shot, which the bridge sends at the real moment of the photo. Each phase
    gives itself up after a while. Protocol 9.
2026-10-01 An RFID card that opens a hidden folder, and the HC-05 out
    An RC522 on SPI1 (A4-A7, RST B1): a card arriving after 1.5 s away is
    EV card <uid> tap, so one left lying on the reader counts once. Double
    tap / hold and a hotel-key slot were tried first and glitched, because a
    resting card drops out of reading for over a second at times. The pet
    drives the RC522's RST itself: the library leaves it floating when it
    reads high, and the chip then never answered. RF test / RF poll check
    the wiring. With the HC-05 gone, the ESP-01's EN moves to A8 (held high)
    to free a 3V3 pin, and the touch pad is powered from B14/B15. The build
    now refuses to grow into the sector where the location is saved.
    Protoco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
    [link.cpp, main.cpp, pet.h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]
2026-10-01 Enclosure: the RFID reader inside the right wall, the head 89.5 deep
    The RC522 stands against the inside of the right wall, antenna end at the
    front, its plugs toward the back, behind a faint ring on the outside where
    the card goes. It hangs with its top in a slot and its bottom in a 45
    degree groove, gripped only along the antenna end, clear of the crystal
    and header. Board, plugs and room for the wires to turn don't fit in 70 mm
    between the round corners, so the depth is now worked out from them
    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
    [base.stl, shell.stl]
2026-10-01 Enclosure: no mark where the card goes, the side stays smooth
    The card opens a hidden folder, and a ring on the outside showing where
    to tap gave it away.
    [shell.stl]
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2026-10-01 Handbook Rev. 2: coding and gaming, selfies, the card, the head, no Bluetooth
    New chapters for the coding and gaming faces, the selfie camera and the
    RFID card, with real captures from firmware v10, and one on the printed
    head with its renders. The rest follows the pet as it is now: WiFi as the
    link to the PC, a bridge that runs at login without Aminal, the wiring
    with the RC522 and the ESP-01 on short wires (no regulator, EN on A8),
    the new protocol lines, multi-link WiFi, and an 8 KB flash margin.
    Bluetooth is gone throughout. 25 pages; the site and PDF are rebuilt.
    The README's intro catches up too.
    [build.py, capture.py, render.py]
2026-10-01 A page for Claude's usage: the session and the week
    CU <session %> <reset> <week %> <reset> gives the pet what Claude's own
    Usage settings show. The new screen sits between the timer and status,
    each row a percentage, a bar and when it resets; from 90% the number
    turns over, the way the app turns it red. It only joins the round once
    numbers have arrived, and says (old) after 20 quiet minutes. Protocol
    11; the handbook and README cover it.
    [capture.py, link.cpp, main.cpp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]
